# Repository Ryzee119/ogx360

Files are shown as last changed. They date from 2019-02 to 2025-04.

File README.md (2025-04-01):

# ogx360 - Overview
  

If you like my work please consider a small donation<br>
<br>

The ogx360 is a small circuit board which allows you to use a range of modern USB controllers on the Original Xbox Console.

* A simple video showing some its feature is on youtube https://youtu.be/ycZjQUjz1Fk
* Another video attempting to show the input lag is here: https://youtu.be/V7Pnba7Y12Y
* Another video showing the Steel Battalion Controller support is here: https://youtu.be/g_eQlOcccg8

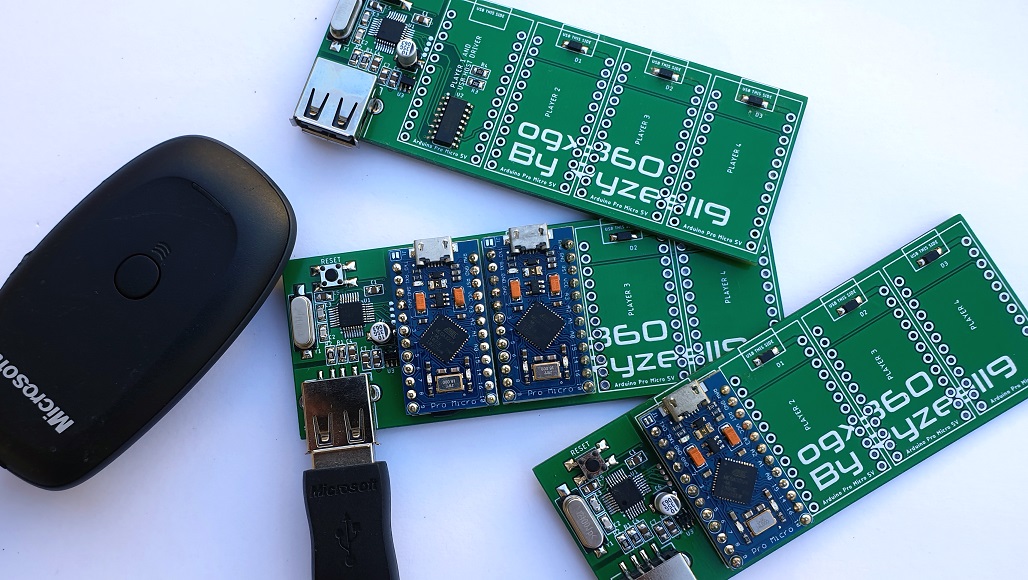
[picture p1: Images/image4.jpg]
ogx360 banner
  

## Features include:
* Full rumble support on all controllers.
* Steel Battalion controller support with an Xbox 360 Chatpad using Xbox 360 Wireless Controllers.
* Low level programming with minimal input lag. Less than 4ms over an original controller. (See https://youtu.be/V7Pnba7Y12Y)
* Firmware can be updated over USB. No programming hardware is required. See [Firmware](./Firmware).
* One ogx360 mutliple Xboxes, just plug the other Arduino modules into nearby OG Xbox consoles.
* Flip the axis on the right stick for those games missing axis inversion settings. (Hold the right stick in then D-PAD to invert that direction).

## Supported controllers
* Supports 4 players with Genuine and Third Party Microsoft Xbox 360 Wireless Receivers.
* Wired Xbox 360 Controllers.
* 8bitdo Wireless Bluetooth Adaptor (See http://www.8bitdo.com/wireless-usb-adapter/ for supported controllers). One controller per 8bitdo adaptor.
* ChronusMAX/ChronusZen (See https://cronusmax.com/ for supported devices). Ensure it is configured to appear as an Xbox 360 Controller. One controller per adaptor.
* Most/all? controllers that are xinput compatible.
* Genuine and PDP Wired Xbox One Controllers.
* Hyperkin Duke Xbox One Controller.
* **NOTE** - When connecting multiple USB bus powered devices, a USB2.0 hub is required. A externally powered hub is recommended.

## Steel Battalion controller emulation
* You need a wireless Xbox 360 controller with a chatpad peripheral.
* You can change what the controller appears to the console at anytime, so you can use the 'Duke Controller' to boot into the game, then change to the 'Steel Battalion controller' whilst in game. 
* Button mapping is below. (High Res image available [here](https://i.imgur.com/12SawzC.png)).

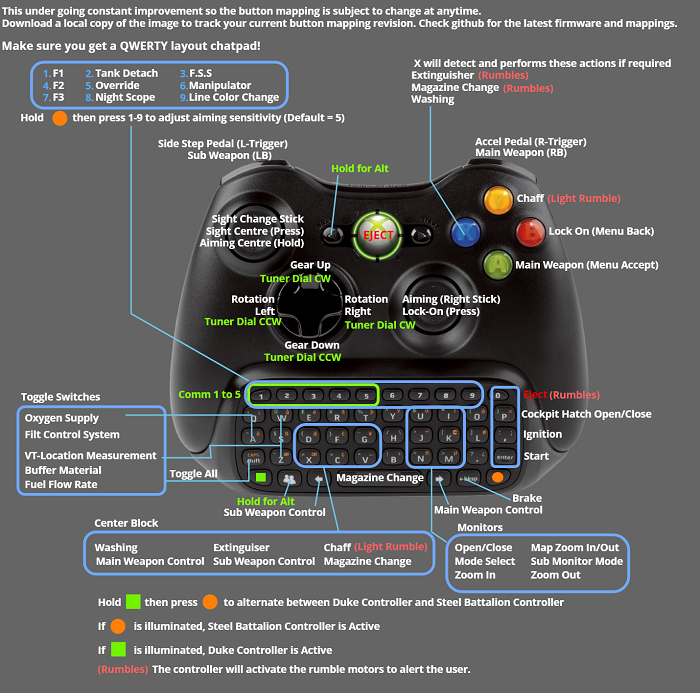
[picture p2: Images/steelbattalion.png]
sbmapping
  

## Connection to your Xbox
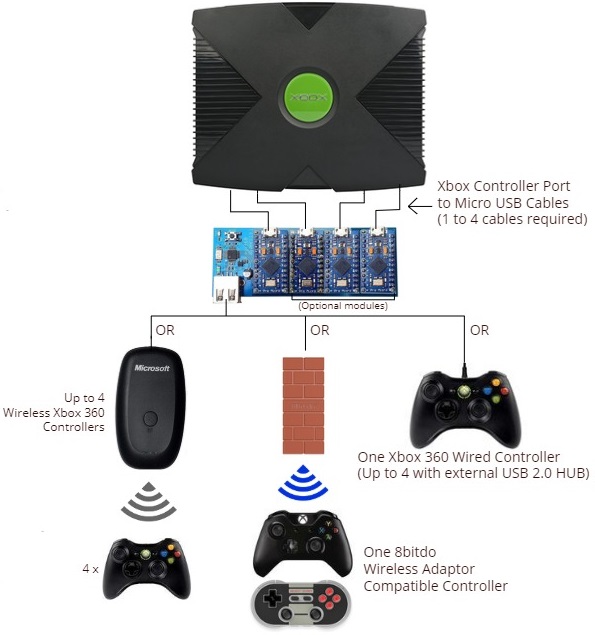
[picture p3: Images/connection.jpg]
connection diagram
  

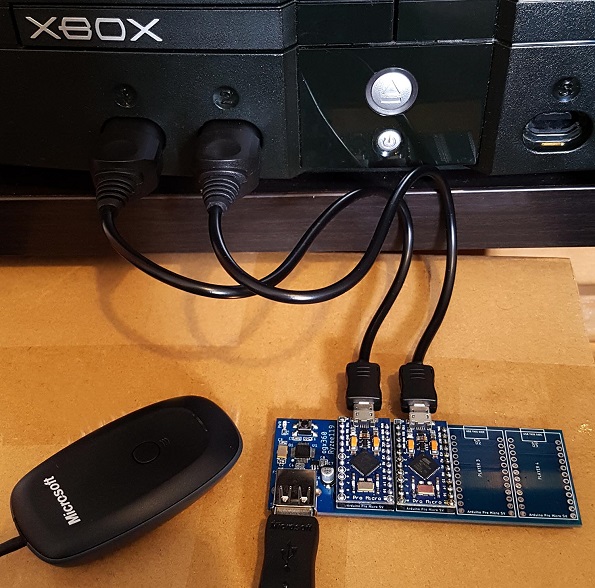
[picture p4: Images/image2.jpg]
ogx360 in use
  

By Ryzee119

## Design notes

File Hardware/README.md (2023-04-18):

# ogx360 - Hardware
This folder contains the schematic and PCB layout files and the PCB Gerber files. These were created using [Autodesk Eagle.](https://www.autodesk.com/products/eagle/overview)

* The PCB Gerbers and BOM are located [here](../.kitspace/).
* These can easily be ordered via [kitspace](https://kitspace.org/boards/github.com/ryzee119/ogx360).
  * Note: you may wish to order extra of the small components (resistors, capacitors, etc.) as it is easy to loose some when hand-soldering.
* 3D model of the PCB is [here](https://a360.co/3aavAXA) (Fusion360).
* Note: On the corner of the Arduino modules there is a solder jumper labelled J1. It is recommended you bridge this with a solder blob.

## Some other needed items
| Qty | Value/Model | Link|
| --- | --- | --- |
| Up to 4 | ARDUINO_LEONARDO_MICRO 5V/16Mhz | [Any clones](https://www.aliexpress.com/item/New-Pro-Micro-for-arduino-ATmega32U4-5V-16MHz-Module-with-2-row-pin-header-For-Leonardo/32768308647.html). Only one is compulsory. 2,3 and 4 will add support for Player 2,3, 4 respectively. Make sure you get the 5V/16Mhz variant. |
| Up to 4 | Xbox Controller Port to MicroUSB cable | [ChimericSystems](https://www.chimericsystems.com/product/micro-usb-to-xbox-cable/) or [Alibaba (Large MOQ!)](https://www.alibaba.com/product-detail/for-XBOX-MicroUSB-Cable-for-Xbox_62222784495.html) or DIY |

## Cases
If you make a case or something similar I can put it here if you're happy to share!
* By bluemeanie23 at [Tinkercad](https://www.tinkercad.com/things/kJb02GCUetG).
* By culexus at [Thingiverse](https://www.thingiverse.com/thing:3510779?fbclid=IwAR1Hd3BBLBxFbMWYJ0MO9VCzgxWrqV2Efiftj0Rz7HYnv9ODGwWncQdSh4I).

## Schematic
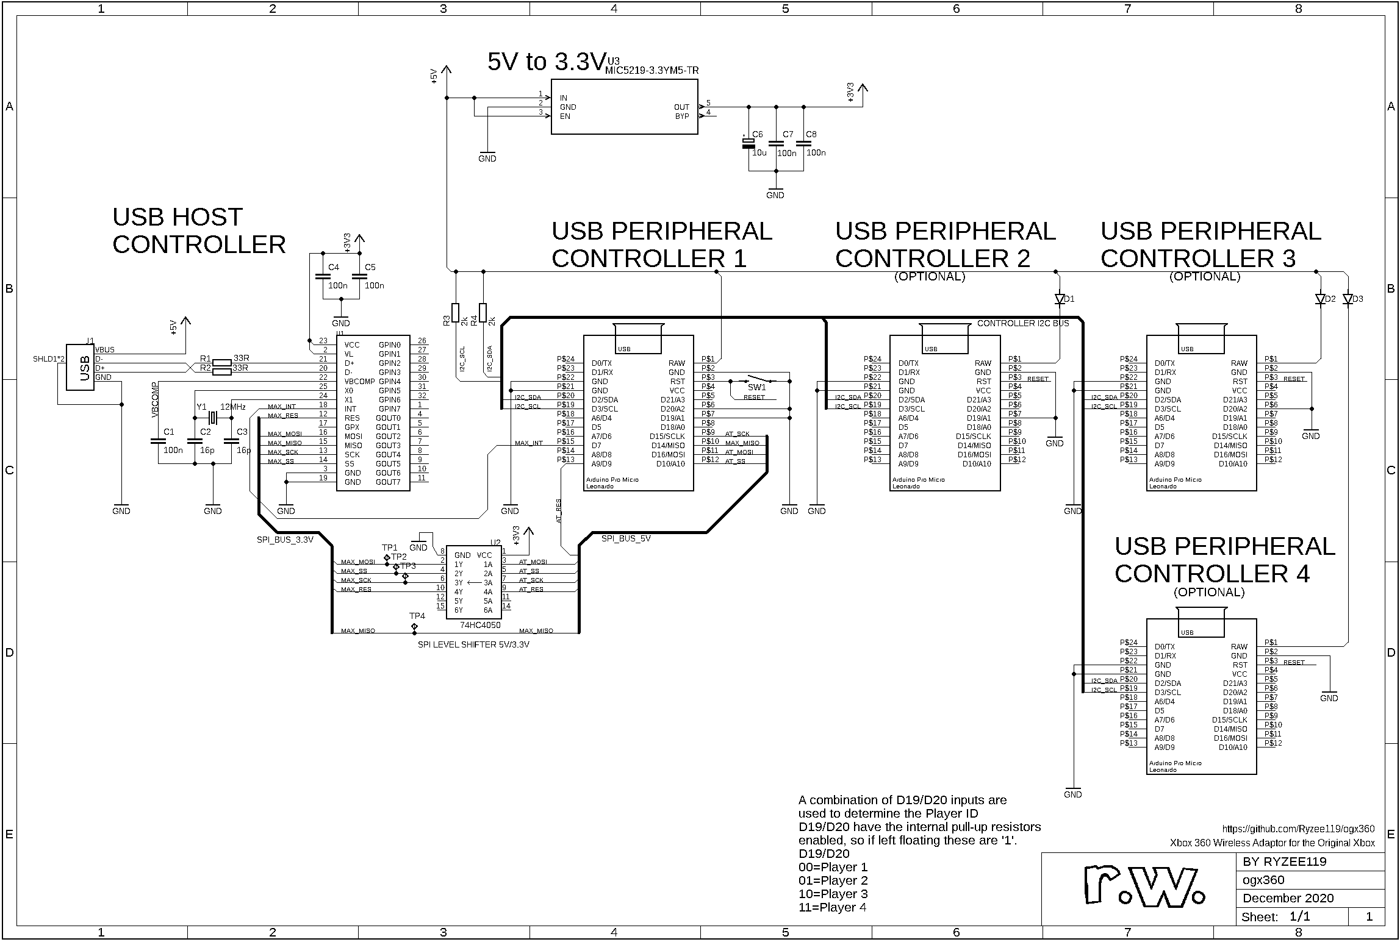
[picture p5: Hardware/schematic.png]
schematic


By Ryzee119

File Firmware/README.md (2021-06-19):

# ogx360 - Firmware

## Programming (Platform IO IDE - Recommended)
* Download and install [Arduino IDE](https://www.arduino.cc/en/software) for the required drivers.
* Setup Visual Studio Code as per the Compiling instructions.
* Press the RESET button on the ogx360 PCB.
* Hit the program button on the Platform IO toolbar (`→`).
* When the console window says `Waiting for the new upload port...` hit the RESET button again.
* Repeat the process for any other modules you need to update.

## Programming (from HEX file)
* Download and install [Arduino IDE](https://www.arduino.cc/en/software) for the required drivers.
* Download [avrdude](http://download.savannah.gnu.org/releases/avrdude/). Windows [download](http://download.savannah.gnu.org/releases/avrdude/avrdude-6.3-mingw32.zip).
* Create a file called `program.bat` in the same folder as `avrdude.exe` and copy this command into it. Note press RESET on the ogx360 and determine what COM number it appears in the device manager and alter the COM17 below as required.
* `avrdude -C avrdude.conf -F -p atmega32u4 -c avr109 -b 57600 -P COM17 -Uflash:w:ogx360.hex:i`
* Press RESET on the ogx360, wait a second then run the bat file.

## Compiling
* Download and install [Arduino IDE](https://www.arduino.cc/en/software) for the required drivers.
* Download and install [Visual Studio Code](https://code.visualstudio.com/).
* Install the [PlatformIO IDE](https://platformio.org/platformio-ide) plugin.
* Clone with git `git clone https://github.com/Ryzee119/ogx360.git --recursive`. Recursively!
* In Visual Studio Code `File > Open Folder... > ogx360/Firmware`
* Hit build on the Platform IO toolbar (`✓`).
* Follow the Programming instructions to program.
* Or see the `.pio/build/` folder for the compiled hex files.

## Testing
If you have made the board yourself and want to check everything is healthy, I have added a test program `ogx360_debug.hex`. Program this to the master module as per the programming instructions under **Programming**.

The module will now appear as a keyboard and serial device in windows. Note the COM port number.

Open a serial monitoring program such as [Termite](https://www.compuphase.com/software_termite.htm), and set the following settings `Baud rate: 115200, 8 Data Bits, 1 Stop Bit, Parity None, Flowing Control RTS/CTS`. Once you connect to the COM Port, the self test should be performed. A healthy board with a Wireless Receiver connected should output the following:

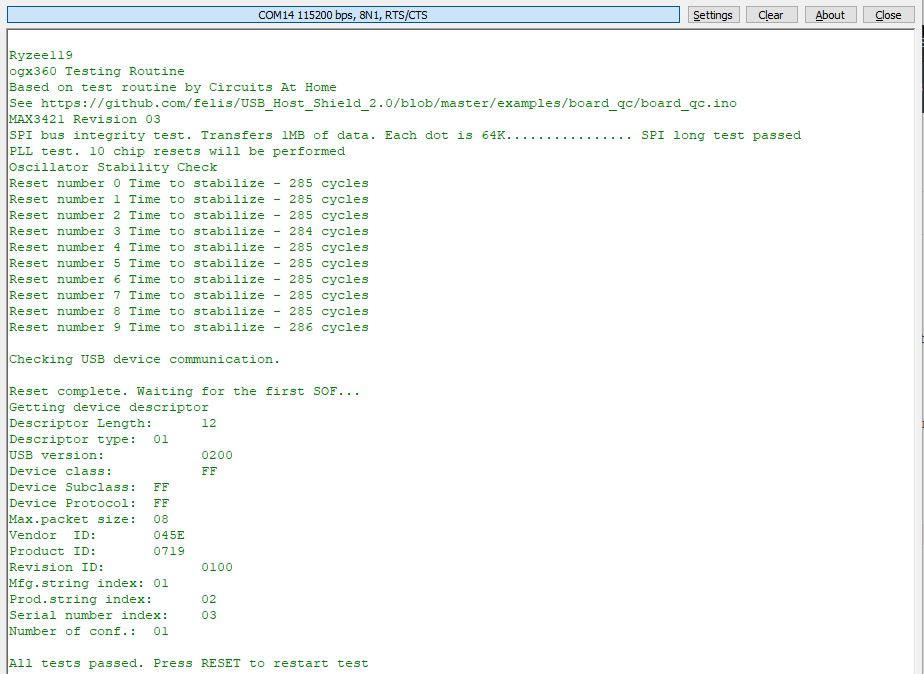
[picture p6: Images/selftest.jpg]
connection diagram
  

## References
* Xbox USB protocol info can be found [here](https://xboxdevwiki.net/Xbox_Input_Devices).
* [USB Host Shield 2.0](https://github.com/felis/USB_Host_Shield_2.0) Library use under the GNU General Public License.
* [Arduino Core](https://github.com/Ryzee119/ArduinoCore-avr) used under the [GNU General Public License/ Lesser GPL](https://github.com/arduino/Arduino/blob/master/license.txt).

By Ryzee119

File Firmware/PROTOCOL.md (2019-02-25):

# Original Xbox Controller USB Protocol Notes
The Original Xbox Controllers actually have a inbuilt 3 port USB hub. One channel is connected to the controller and the other two connect to the expansion ports on top of the controller.

The controller basically is a standard 'Human Input Device Class' as defined by the [USB Definition](https://www.usb.org/hid), however implement some custom vendor requests and are required for the controller to be detected correctly on an Original Xbox Console. The Original Xbox controller also does not have a HID Report Descriptor, consequently will not work in a Windows machine via a USB adaptor without custom drivers.
My code does not emulate the USB Hub and enumerates as the controller directly. The Xbox console doesn't seem to care.

A device descriptor dump from my Original Controller can be seen [here](https://github.com/Ryzee119/ogx360/tree/master/Firmware/DescriptorDump_VID045E_PID0289.md). There's a few variations around the world it seems, infact my own two controllers had slightly different descriptors but I guess all would work the same.
The device descriptor and the below responses are coded in `dukecontroller.h`.

### USB Controller Descriptor
Information for device USB\Vendor_045E_Product_0289:

Connection Information:
------------------------------
Device current bus speed: FullSpeed

Device supports USB 1.1 specification

Device address: 0x000B

Current configuration value: 0x01

Number of open pipes: 2

Device Descriptor:
------------------------------
0x12	bLength

0x01	bDescriptorType

0x0110	bcdUSB

0x00	bDeviceClass      

0x00	bDeviceSubClass   

0x00	bDeviceProtocol   

0x08	bMaxPacketSize0   (8 bytes)

0x045E	idVendor

0x0289	idProduct

0x0121	bcdDevice

0x00	iManufacturer

0x00	iProduct

0x00	iSerialNumber

0x01	bNumConfigurations

Configuration Descriptor:
------------------------------
0x09	bLength

0x02	bDescriptorType

0x0020	wTotalLength   (32 bytes)

0x01	bNumInterfaces

0x01	bConfigurationValue

0x00	iConfiguration

0x80	bmAttributes   (Bus-powered Device)

0x32	bMaxPower      (100 mA)

Interface Descriptor:
------------------------------
0x09	bLength

0x04	bDescriptorType

0x00	bInterfaceNumber

0x00	bAlternateSetting

0x02	bNumEndPoints

0x58	bInterfaceClass      

0x42	bInterfaceSubClass   

0x00	bInterfaceProtocol   

0x00	iInterface

Endpoint Descriptor:
------------------------------
0x07	bLength

0x05	bDescriptorType

0x81	bEndpointAddress  (IN endpoint 1)

0x03	bmAttributes      (Transfer: Interrupt / Synch: None / Usage: Data)

0x0020	wMaxPacketSize    (1 x 32 bytes)

0x04	bInterval         (4 frames)

Endpoint Descriptor:
------------------------------
0x07	bLength

0x05	bDescriptorType

0x02	bEndpointAddress  (OUT endpoint 2)

0x03	bmAttributes      (Transfer: Interrupt / Synch: None / Usage: Data)

0x0020	wMaxPacketSize    (1 x 32 bytes)

0x04	bInterval         (4 frames)

Microsoft OS Descriptor is not available. Error code: 0x0000001F

String Descriptor Table
--------------------------------
Index  LANGID  String

0x00   0x0000  

### HID Input Report (The data that is sent to the host when the host requests the HID Report)
| byte | Data |
| --- | --- |
| 00 | 0x00 - Always 0x00 |
| 01 | 0x14 - Size of the report. 0x14 = 20 bytes long |
| 02 | Each bit in the byte represents the Controller digital buttons.*|
| 03 | 0x00 - Always 0x00 |
| 04 | A Button (Analog button, unsigned char) 0x00 to 0xFF |
| 05 | B Button (Analog button, unsigned char) 0x00 to 0xFF |
| 06 | X Button (Analog button, unsigned char) 0x00 to 0xFF |
| 07 | Y Button (Analog button, unsigned char) 0x00 to 0xFF |
| 08 | BLACK Button (Analog button, unsigned char) 0x00 to 0xFF |
| 09 | WHITE Button (Analog button, unsigned char) 0x00 to 0xFF |
| 10 | L Trigger (Analog button, unsigned char) 0x00 to 0xFF |
| 11 | R Trigger (Analog button, unsigned char) 0x00 to 0xFF |
| 12/13 | Left Stick X-Axis (Analog, signed short 16-bit) |
| 14/15 | Left Stick Y-Axis (Analog, signed short 16-bit) |
| 16/17 | Right Stick X-Axis (Analog, signed short 16-bit) |
| 18/19 | Right Stick Y-Axis (Analog, signed short 16-bit) |

\* bit 0 to bit 7 = D-Pad Up, D-Pad Down, D-Pad Left, D-Pad Right, Start, Back, Left Stick Button, Right Stick Button

## HID Output Report (The data that is sent from the host. i.e rumble updates)
| byte | Data |
| --- | --- |
| 00 | 0x00 - Always 0x00 |
| 01 | 0x06 - Size of the report. 6 bytes long |
| 02 | 0x00 - Always 0x00 |
| 03 | Left Rumble Value (Analog, unsigned char) 0x00 to 0xFF |
| 04 | 0x00 - Always 0x00 |
| 05 | Right Rumble Value (Analog, unsigned char) 0x00 to 0xFF |

## XID Descriptor - Custom Vendor Request
This is what I obtained when monitoring the USB bus between the controller and the console.
The controller responds with this when `bmRequestType = 0xC1, bRequest = 0x06 and wValue = 0x4200` from the host.

| byte | Data |
| --- | --- |
| 00 | 0x10 - bLength, Length of report. 16 bytes |
| 01 | 0x42 - bDescriptorType, always 0x42 |
| 02 & 03 | 0x00, 0x01 - bcdXid  |
| 04 | 0x01 - bType - 1=Xbox Gamecontroller, 0x80 = Steel Battalion |
| 05 | 0x02 - bSubType, 0x01 = Gamepad (Duke), 0x02 = Gamepad S/Steel Battalion, 0x10 = Wheel.. |
| 06 | 0x14 - bMaxInputReportSize |
| 07 | 0x06 - bMaxOutputReportSize |
| 08 to 15 | 8 x 0xFF - wAlternateProductIds |

## HID Capabilities IN - Custom Vendor Request
This is what I obtained when monitoring the USB bus between the controller and the console.
The controller responds with this when `bmRequestType = 0xC1, bRequest = 0x01 and wValue = 0x0100` from the host.
It will have bits set (1) where the bit is valid in the HID Input Report.
If the bit is auto-generated, it will be cleared (0). Refer http://xboxdevwiki.net/Xbox_Input_Devices

| byte | Data |
| --- | --- |
| 00 | 0x00 - Always 0x00 |
| 01 | 0x14 - Size of the report. 0x14 = 20 bytes long |
| 02 | 0xFF |
| 03 | 0x00 |
| 04 to 19 | 16 x 0xFF |

## HID Capabilities OUT - Custom Vendor Request
This is what I obtained when monitoring the USB bus between the controller and the console.
The controller responds with this when `bmRequestType = 0xC1, bRequest = 0x01 and wValue = 0x0200` from the host.
It will have bits set (1) where the bit is valid in the HID Output Report.
If the bit is auto-generated, it will be cleared (0). Refer http://xboxdevwiki.net/Xbox_Input_Devices

| byte | Data |
| --- | --- |
| 00 | 0x00 - Always 0x00 |
| 01 | 0x06 - Size of the report. 6 bytes long |
| 02 to 05 | 4 x 0xFF |

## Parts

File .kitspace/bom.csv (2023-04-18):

Reference | Qty | Description | Part Number | Manufacturer | Digikey
C1,C4,C5,C7,C8 | 5 | CAP 100NF, 0805 | CC0805ZRY5V9BB104 | Yageo | 311-1361-1-ND
C2,C3 | 2 | CAP 16PF, 0805 | CC0805JRNPO9BN160 | Yageo | 311-4228-1-ND
C6 | 1 | CAP ALUM, 10UF SMD | EDK106M035A9BAA | KEMET | 399-14794-1-ND
D1,D2,D3 | 3 | DIODE SCHOTTKY, SOD123 | BAT54GWJ | Nexperia USA Inc. | 1727-7328-1-ND
J1 | 1 | USB CONNECTOR, TYPEA, SMD | AU-Y1006 | Assmann WSW Components | AE11182-ND
R1,R2 | 2 | RES, 33OHM, 1%, 0805 | RC0805FR-0733RL | Yageo | 311-33.0CRCT-ND
R3,R4 | 2 | RES, 2KOHM, 0805 | RC0805JR-072KL | Yageo | 311-2.0KARCT-ND
SW1 | 1 | SWITCH TACTILE SPST-NO | TL3305AF160QG | E-Switch | EG5350CT-ND
Y1 | 1 | CRYSTAL 12.0000MHZ 18PF SMD | J49SMH-F-G-G-K-12M0 | Jauch Quartz | 1908-J49SMH-F-G-G-K-12M0CT-ND
U1 | 1 | MAX3421 USB HOST CNTRL 32TQFP | MAX3421EEHJ+T | Maxim Integrated | MAX3421EEHJ+TCT-ND
U2 | 1 | IC BUFFER NON-INVERT 16SOIC | 74HC4050D | Toshiba Semiconductor and Storage | 74HC4050DCT-ND
U3 | 1 | IC REG LINEAR 3.3V 500MA SOT23-5 | MIC5219-3.3YM5-TR | Microchip Technology | 576-1281-1-ND

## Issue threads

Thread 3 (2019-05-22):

Rumble makes controller disconnect

TEK-Nemesis, 2019-05-22:
Area 51 with rumble on makes the controller disconnect on every rumble.  Turning rumble off solves the issue.

Only one wireless controller was connected.
Rev 1.0 board.  128MB RAM.  X3CE modchip using X2 5035.
Genuine Xbox 360 controller with genuine receiver.

Ryzee119, 2019-05-22:
Thanks foe the feedback
Is it only that game? Have you tried new batteries in the wireless controller?

TEK-Nemesis, 2019-05-22:
I only tried that game last night.

One battery (Panasonic alkaline) is at 1.52v; the other is at 1.14v (for a total of 2.66v).  Will replace both with Duracell alkaline batteries at 1.61v each (for a total of 3.22v).

(My gut feeling is that this will work.  I'll report back once tested.)

TEK-Nemesis, 2019-05-22:
Area 51 tests perfectly with rumble.  Thanks for your quick assessment!

Ryzee119, 2019-05-23:
No problem, I will look into mayble disabling rumble on low battery levels automatically to prevent this happening and extend controller life

Closed 2019-05-22.

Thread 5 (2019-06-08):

Grey 8Bitdo USB Adapter Support

SlowCatalyst, 2019-06-08:
Is the grey 8bitdo USB adapter supported as well?

I remember talking with you recently about the n360, in that there was a possibility of 8bitdo USB adapters being implemented to the firmware, but the grey model was a bit up in the air.

I just received my ogx360 [this thing is fkn beautiful by the way- amazing job]- hooked up the grey 8bitdo USB adapter, and NES30 Pro connected to it fine, however there is no input detected.

Am I missing a simple step, or does the grey USB infact have a different device signature- or something of that nature- from the orange variant USB adapter?

Ryzee119, 2019-06-08:
Only the orange adaptor has been tested.
If you can provide a usb descriptor dump from a windows PC and I can have a look at it to see how it differs.
I dont own a grey one to test

Evelsnake, 2019-08-03:
[DescriptorDump_Controller.txt](https://github.com/Ryzee119/ogx360/files/3463269/DescriptorDump_Controller.txt)

Information for device Controller (VID=0x054C PID=0x0CDA):

Connection Information:
------------------------------
Device current bus speed: FullSpeed
Device supports USB 1.1 specification
Device supports USB 2.0 specification
Device address: 0x0002
Current configuration value: 0x01
Number of open pipes: 2

Device Descriptor:
------------------------------
0x12	bLength
0x01	bDescriptorType
0x0200	bcdUSB
0x00	bDeviceClass
0x00	bDeviceSubClass
0x00	bDeviceProtocol
0x40	bMaxPacketSize0   (64 bytes)
0x054C	idVendor
0x0CDA	idProduct
0x0100	bcdDevice
0x01	iManufacturer   "Sony Interactive Entertainment"
0x02	iProduct   "Controller"
0x00	iSerialNumber
0x01	bNumConfigurations

Configuration Descriptor:
------------------------------
0x09	bLength
0x02	bDescriptorType
0x003B	wTotalLength   (59 bytes)
0x02	bNumInterfaces
0x01	bConfigurationValue
0x00	iConfiguration
0xA0	bmAttributes   (Bus-powered Device, Remote-Wakeup)
0x32	bMaxPower      (100 mA)

Interface Descriptor:
------------------------------
0x09	bLength
0x04	bDescriptorType
0x00	bInterfaceNumber
0x00	bAlternateSetting
0x01	bNumEndPoints
0x03	bInterfaceClass      (Human Interface Device Class)
0x00	bInterfaceSubClass
0x00	bInterfaceProtocol
0x00	iInterface

HID Descriptor:
------------------------------
0x09	bLength
0x21	bDescriptorType
0x0111	bcdHID
0x00	bCountryCode
0x01	bNumDescriptors
0x22	bDescriptorType   (Report descriptor)
0x0031	bDescriptorLength

Endpoint Descriptor:
------------------------------
0x07	bLength
0x05	bDescriptorType
0x81	bEndpointAddress  (IN endpoint 1)
0x03	bmAttributes      (Transfer: Interrupt / Synch: None / Usage: Data)
0x0040	wMaxPacketSize    (1 x 64 bytes)
0x0A	bInterval         (10 frames)

Interface Descriptor:
------------------------------
0x09	bLength
0x04	bDescriptorType
0x01	bInterfaceNumber
0x00	bAlternateSetting
0x01	bNumEndPoints
0x03	bInterfaceClass      (Human Interface Device Class)
0x00	bInterfaceSubClass
0x00	bInterfaceProtocol
0x00	iInterface

HID Descriptor:
------------------------------
0x09	bLength
0x21	bDescriptorType
0x0110	bcdHID
0x00	bCountryCode
0x01	bNumDescriptors
0x22	bDescriptorType   (Report descriptor)
0x0032	bDescriptorLength

Endpoint Descriptor:
------------------------------
0x07	bLength
0x05	bDescriptorType
0x82	bEndpointAddress  (IN endpoint 2)
0x03	bmAttributes      (Transfer: Interrupt / Synch: None / Usage: Data)
0x0040	wMaxPacketSize    (1 x 64 bytes)
0x0A	bInterval         (10 frames)

Microsoft OS Descriptor is not available. Error code: 0x0000001F

String Descriptor Table
--------------------------------
Index  LANGID  String
0x00   0x0000  0x0409
0x01   0x0409  "Sony Interactive Entertainment"
0x02   0x0409  "Controller"

------------------------------

Connection path for device:
Intel(R) 6 Series/C200 Series Chipset Family USB Enhanced Host Controller - 1C26
Root Hub
Generic USB Hub
Controller (VID=0x054C PID=0x0CDA) Port: 5

Running on: Windows 10 or greater

Brought to you by TDD v2.11.0, Mar 26 2018, 09:54:50

Ryzee119, 2019-08-03:
Thanks mate, appreciate it.
It enumerates as a PS Classic controller; this is currently not implemented and it's completely different from the Orange 8bitdo adaptor (which is supported). So won't work yet.

Doesn't look difficult to write a driver for it, but I won't be able to commit to anything yet. I'm also at the complete limits of Flash memory available

Ryzee119, 2019-08-11:
ok as a workaround in the interim, if anyone has the grey 8btido adaptor, I have a theory that the firmware from the orange unit can be written to it.
You can download the firmware for the orange unit from here:
https://support.8bitdo.com/

It is completely reversible.

I have tested converting my orange adaptor to the grey one myself. But no this way around. I assume it works the same.

CroCop86, 2019-08-11:
I have flashed the orange Firmware to the grey unit, but ogx360 won't recognize it

Ryzee119, 2019-08-11:
Thanks for testing @CroCop86. Well there goes that theory 😄 . I will be getting the grey adaptor soon so can do some testing from it too

Ryzee119, 2019-08-24:
So I got my grey adaptor and if I manually update the firmware with the firmware for the Orange adaptor it works for me https://download.8bitdo.com/Firmware/Receiver/usb_adapter/8BitDo_USB_RR_Firmware_V1.27.zip

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

Ryzee119, 2019-08-24:
If it doesn't work try updating to the latest firmware. I have improved some timings which may make a difference.

Kilerz28, 2020-01-18:
Hey. I have done what you said here @Ryzee119 and it works for me. I have the gray adapter and it pairs with my xbox one controller. Thanks.

Ryzee119, 2020-03-15:
Closed, as it is simple to write the orange/brown unit fimmware to the grey device so that it works.

Closed 2020-03-15.

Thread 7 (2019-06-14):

Migrate to UHS3.0

Ryzee119, 2019-06-14:
Currently the ogx360 firmware uses the USB Host Shield 2.0 library. This is polling based and has lots of inherent issues meeting USB timing specifications. It has many hacks to get things reliably working. Endpoints writes dont always work as expected (i.e the wrong controller rumbles or the LED's dont work correctly)

UHS3.0 is interrupt driven and does not suffer from these inherent problems. Ideal plan is to migrate the code to this new library.
Challenges:
UHS3 does not have any Xbox drivers - these will need to be created and ideally upstreamed
ogx360 max3421 interrupt pin isnt actually connected to the Arduino on the PCB (I should have planned ahead better!) . work around?
Significant rewrite required but hopefully a much more reliable solution.

Ryzee119, 2020-12-08:
Ive ported UHS3 and got it running, however the 32u4 just doesnt have enough RAM to get it working.
It fails on most memory allocations and this is before ive even added in the device stack.

I unfortunately dont think it is possible to put this on the 32u4 :(

Closed 2020-12-08.

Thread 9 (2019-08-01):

3 pad RED LED 67-1556-1-ND

tai1976, 2019-08-01:
Had some boards made up from OSHPark and used your Digikey quick cart and everything went and works well. However, the 3 pad RED LED 67-1556-1-ND has really thrown me for a loop.
I believe the center pad is for heat dissipation which can increase brightness at lower voltages and the overall life of the LED but your PCB layout only has 2 pads for the anode and cathode and I was concerned the center pad could possibly short both pads.
So my question is this. Why use a 3 pad LED with only 2 pads on the PCB?
Was 67-1556-1-ND originally a 2 pad LED? Should I solder the LED a bit off center so that the center pad dissipates through the anode or cathode or am I just missing something?

Ryzee119, 2019-08-02:
That's interesting, 67-1556-1-ND wasn't a 3-pad LED in my prototyping from memory.
It's unclear exactly what that 3rd pad is, just mechanical support I guess, and some heat dissipation but that wont be a concern for this.

I'd say that centre pad can remain unconnected. I will update that part to a more standard 0805 LED. It wont impact the operation of the board in anway, purely a power indication LED (But the arduinos have this anyway)

Thank you for highlighting the issue.

tai1976, 2019-08-02:
Thank you for getting back. That is what I thought. I just used a standard 0603 LED I already had on hand and swapped R5 for a 220 Ohm resistor to increase the brightness.
Thank you so much for making and publishing this project. This is truly a must have/make for any OG Xbox fan.

Ryzee119, 2019-08-03:
Closed by PR #9fa276d

Closed 2019-08-03.

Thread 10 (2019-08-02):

generic wireless adapter not syncing

loggio, 2019-08-02:
Hi, @Ryzee119

I have obtained an OGX360 and can't thank you enough for all your hard work. It's awesome!

I'm having issues however... I have a generic wireless adapter off eBay.
It will allow me to sync 3 of my xbox 360 controllers to the OGX360, but the other 4 controllers i have do not sync. Funny enough all of the controllers that i cannot get to sync are all white version controllers (could be just coincidence). Maybe they're older models??

I suspect that your driver support is not working for certain versions of the 360 controller. A handshake miss-match so to speak.

When the ogx360 is plugged in to the control ports of the XBOX, i push the sync buttons and the controller will acknowledge the dongle as it stops the sync process and begins the quick pulse handshake, the master controller of the OGX360 will briefly flash red and then disappear as if it cannot pair with the controller.... This loop continues over and over until the controller battery is pulled.

If i plug this receiver into my windows 10 computer and install the genuine microsoft driver for the dongle, i can sync the controllers just fine to my PC.

All of my controllers work perfectly and sync with the PC and the XBOX 360. But only 4 out f my 7 controllers will sync successfully with the OGX360, the other 3 will not.

Is there any information i can supply you that will help with diagnosing this problem ?
hopefully a firmware update will fix this.

Ryzee119, 2019-08-02:
Hey mate,
Thanks for the details response.
Its possible there is some differences that Im not aware of.

Out of curiosity, the controllers that don't appear to sync, have you checked if the buttons etc. actually work still?
Its possible its just the LED thats not setting to a quadrant correctly.

If the controllers don't work at all we can look into it a bit further

loggio, 2019-08-02:
They don't work at all. The controllers will recognise the dongle but won't sync at all.

Ryzee119, 2019-08-02:
My understanding was that all the syncing and negotiations was handled by the receiver. The driver doesn't do any of that so this is an interesting one.

I'll have to do some digging this weekend to see how the windows driver handshakes and if im doing anything differently.

loggio, 2019-08-02:
Yes it's weird. They're all genuine controllers. The only thing different is the Chinese dongle. Though like I said, the same dongle syncs the controllers fine on Windows pc.

And the controllers sync fine on my xbox 360. Just not the Ogx360.

Let me know if you need me to do any further testing.

Ryzee119, 2019-08-06:
So i've dumped the USB traffic going to the wireless receiver in Windows on connection of the Xbox 360 controller.

The following packets are sent to the respective endpoint (1,3,5 or 7 depending on the controller)
00 00 08 40 00 00 00 00 00 00 00 00 //Turn LED off

00 00 08 42 00 00 00 00 00 00 00 00 //Set LED to blink. 0x42 is for quadrant 1

00 00 02 80 00 00 00 00 00 00 00 00 //Unknown?

00 00 00 40 00 00 00 00 00 00 00 00 //Update battery level I think

00 00 08 46 00 00 00 00 00 00 00 00 //Set LED to solid on for quadrant 1

It also polls every 2.5 seconds, but I think this is just to update the battery level or some kind of status to the windows driver.

I have implemented this init sequence exactly as per the windows driver

[ogx360_issue10.zip](https://github.com/Ryzee119/ogx360/files/3471615/ogx360_issue10.zip)

If you are able to test this firmware and report back that would be awesome!

Programming instructions are here

https://github.com/Ryzee119/ogx360/tree/master/Firmware#programming

loggio, 2019-08-06:
just tested and still no difference. Cannot sync

loggio, 2019-08-06:
i do have a microsoft branded dongle coming in the mail... When i receive that i will test and report back. Will be interesting if it is the dongle.

But as i said, the dongle works fine on the PC syncing with all my controllers using the official microsoft drivers. So not sure what could be causing this.

The controllers seem to sync with the dongle, but they won't latch on to a port. you can see that one micro controller will light up for briefly and then disappear

Ryzee119, 2019-08-06:
Thanks for your prompt testing
That will be very interesting to see if the genuine one works
I'm also curious to know if it works in Linux as my driver is loosely based on the xpad driver in Linux.

loggio, 2019-08-06:
Ok,  I can test on Ubuntu. Hopefully it's just plug and play. I will do this tomorrow.

loggio, 2019-08-06:
So, just to summaries...

 My steps

1. Turn on xbox. Wait for boot.
2. Attach dongle
3. Attach master to Port 1 of xbox
4. Turn on controller, press sync.
5. Press sync on dongle.

Results.

After pressing sync on both controller and dongle, the controller will very quickly sync with the dongle as the controller stops the sync cycle and starts to flash.

I see the master controller of the Ogx360 flash red briefly, but won't latch on. The controller will just sit in a pairing (flashing) state until switched off. Slave controllers act the same.

The handshake between the controller, dongle and Port assignments seems to not want to cooperate.

It sounds very much like I'm using different versions of controllers and some of which are incompatible with the drivers.

I just can't see why some controllers work fine, and others won't.

Ryzee119, 2019-08-06:
Thanks for the summary, I'll have a think about it and see if I can come up with anything in the meantime too

loggio, 2019-08-07:
So, i've layed out all my controllers. the three white controllers stacked are the ones that do not work.

Interestingly enough, they are a different model number to the rest - model MSK-WC01

The black controllers and the silver controllers are model number MSK-1403
The single white controller is model number  MSK-XBOX360WLSCTLR

All work on PC and seem to sync with the dongle.
only model number MSK-WC01 will not work with your OGX360.

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

I have yet to try with Ubuntu. Will do this shortly.

loggio, 2019-08-07:
Ok, the controller syncs and works fine on Ubuntu.
See videos below.

[videos.zip](https://github.com/Ryzee119/ogx360/files/3475838/videos.zip)

Ryzee119, 2019-08-07:
legend mate, thanks once again for the detailed response. I'll review/test and see what I come up with!
Unfortunately all my controllers are MSK-1403, so there's something interesting going on with that model I guess

loggio, 2019-08-07:
One thing I noticed is that it took a little while to assign a quadrant for the controller on Ubuntu... Maybe this model takes a little longer to sync up?

Might be a timing thing perhaps?

Ryzee119, 2019-08-09:
[ogx360_issue10_1.zip](https://github.com/Ryzee119/ogx360/files/3485933/ogx360_issue10_1.zip)
Ok, so I tweaked some timing to match the Windows driver more closely, and also changed all my packet sizes to 12 bytes.

Ryzee119, 2019-08-09:
You probably only need to update the MASTER device for this, so no need to update all modules

loggio, 2019-08-09:
Hmm it's still not working.

However, it seems to latch for a second or two longer and more frequently ... Enough to register a quadrant but won't lock on.

Ryzee119, 2019-08-09:
wow those are some picky controllers. I think I'm replicating the Windows driver exactly. Last thing to see is if the genuine receiver makes a difference

loggio, 2019-08-09:
It's definitely trying a lot harder

Ryzee119, 2019-08-09:
The controller's not turning off right? Just disconnecting?

loggio, 2019-08-09:
Hmm yes I can try this. It was due to be delivered today but I missed the delivery so I have to pick it up from the post office, however I'm working away next week so I won't be able to test it till I'm back for the weekend

loggio, 2019-08-09:
Just disconnecting, trying over and over to connect. I can see now it will connect, flash a quadrant, and then disconnect... Sometimes reconnecting again a second later only to disconnect again.

Ryzee119, 2019-08-09:
[ogx360_issue10_2.zip](https://github.com/Ryzee119/ogx360/files/3486046/ogx360_issue10_2.zip)
No worries, sorry to be bothering with different files but you could also try this one to see if it makes a difference

loggio, 2019-08-09:
So the symptoms have changed slightly, it's an improvement... Maybe the timing needs to be tweaked beyond default ms drivers?

loggio, 2019-08-09:
No difference

Ryzee119, 2019-08-09:
thanks again, I might see if I can source one of these controllers or ask around if anyone can test their ogx360 with that revision.

loggio, 2019-08-09:
And you're not bothering me mate, happy to be testing. You can keep sending me files

loggio, 2019-08-09:
No way! It just synced.

I waited for a quadrant to flash and then quickly pushed a button and it locked on and stayed connected.

Once I turn the controller off and back on  it struggles to connect again

Ryzee119, 2019-08-09:
Does it help if you're moving an analog stick around whilst it is syncing?
This forces the controller to send interrupt transfers and might help it connect

loggio, 2019-08-09:
I haven't been able to get it to sync again. I can try this again

loggio, 2019-08-09:
Didn't help...

loggio, 2019-08-09:
In case you're interested
This is the dongle I purchased.
https://rover.ebay.com/rover/0/0/0?mpre=https%3A%2F%2Fwww.ebay.com.au%2Fulk%2Fitm%2F322228480691

loggio, 2019-08-09:
Also,

If you're interested, I've found 3 ebay listing with the controller. 1# finishing later today. All buy it now.

1. https://rover.ebay.com/rover/0/0/0?mpre=https%3A%2F%2Fwww.ebay.com.au%2Fulk%2Fitm%2F264316811936

2. https://rover.ebay.com/rover/0/0/0?mpre=https%3A%2F%2Fwww.ebay.com.au%2Fulk%2Fitm%2F143347474356

3. https://rover.ebay.com/rover/0/0/0?mpre=https%3A%2F%2Fwww.ebay.com.au%2Fulk%2Fitm%2F283557924170

Ryzee119, 2019-08-09:
Awesome, #1 ordered!

loggio, 2019-08-09:
Just make sure you ask the seller to make sure the model number is exactly as pictured!!!

I just noticed he has a max quantity of 2... Meaning he's selling more than one.

I've had it where the item they send is different to the one pictured.

loggio, 2019-08-10:
Ok, I'm very happy to report that I just picked up my official Microsoft adapter (post office is open for a few hours) and all the controllers sync up perfectly and instantly!

So it is definitely the cheap adapter.

Would still be good to continue troubleshooting this as I'm guessing in the future a lot of people will have no choice but to buy cheap adapters as the official ones are no longer available.

Ryzee119, 2019-08-10:
Fantastic news, I have this version of controller enroute and a few different receivers to try. If I can replicate the issue I should be able to solve it!

Ryzee119, 2020-12-14:
The XBOXRECV driver has been reworked significantly. If anyone had this issue please retry and report back.

Will close issue in a few weeks if no reports. Reopen if still present :)

Closed 2021-01-01.

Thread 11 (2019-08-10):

8Bitdo Adapter not working

CroCop86, 2019-08-10:
I have 2 orange and 2 grey 8Bitdo receiver and i can't get anyone to work. Can you help me please somehow?

I have attached the logfile from USB Descriptor Dumper as a textfile

[8Bitdo Receiver.txt](https://github.com/Ryzee119/ogx360/files/3489209/8Bitdo.Receiver.txt)

Ryzee119, 2019-08-11:
Hello,
Interestingly all the descriptor dumps provided look like they're  from a grey adaptor. Not an orange one.

Are these descriptor dumps being  taken from a windows machine?
The Orange adaptors traditionally, enumerate as a Xbox360 wired controller,
The greys enumerate as a generic Playstation controller.

I think I will need to pickup one of these grey units and add support for it.

Ryzee119, 2019-08-11:
You could try udating your orange 8bitdo device to the latest firmware https://support.8bitdo.com/firmware-updater.html

The grey unit is significantly different, so is not currently supported

CroCop86, 2019-08-11:
Thank you for your fast answer. I have updated all four to the latest firmware through the universal 8bitdo updater. I will try to flash them with their own updater:
8BitDo_USB_RR_Firmware_V1.26
8BitDo_USB_RR_FOR_PS_Firmware_V1.26

And maybe downgrade them. If you could add support for the grey ones too, would be really appreciate :)

CroCop86, 2019-08-11:
I have downgrade from Firmware v1.27 to v1.26, now the orange receiver work both. I have attached again the log File for you, so you can see what changed after the downgrade.

Thank you again for your help :)
[8Bitdo Orange after downgrade to FW 1.26.txt](https://github.com/Ryzee119/ogx360/files/3489730/8Bitdo.Orange.after.downgrade.to.FW.1.26.txt)

Ryzee119, 2019-08-11:
That log file looks much better.
So I just did some testing and it is actually possible to write the firmware for the grey unit onto the orange unit (causing incompatibility with the ogx360).
The auto update will then just assume the grey unit and auto update accordingly (and incorrectly).

I would assume now that if you run the auto update tool now that you've written the correct firmware it will work as expected.

I wonder if somehow the firmware got mixed up at some point

CroCop86, 2019-08-11:
I'm not sure how it got mixed up, but for the first time i tried the beta Firmware 1.27 and still the orange icon was shown above the updater. Maybe that was the problem. Downgrading to 1.26 for the orange unit resolved it however. Are you still planing to add support for the grey units?

Ryzee119, 2019-08-11:
I have ordered a grey unit so will see what I can do in the upcoming weeks

Ryzee119, 2019-08-11:
I will mark this issue as closed but will link existing issue #5 for grey 8bitdo adaptor support.

Closed 2019-08-11.

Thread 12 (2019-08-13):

404 on bill of materials usb controller link

RobertDaleSmith, 2019-08-13:
Thanks for the awesome work here. Looking into building my own unit and noticed one of the Digi-Key links is dead. Would this be a good alternative to the usb host controller?

https://www.digikey.com.au/product-detail/en/maxim-integrated/MAX3421EEHJ-T/MAX3421EEHJ-TTR-ND/1455882

Ryzee119, 2019-08-14:
Hello,

Looks good! However I suggest his link. The same part but allows single units to be purchased and is in stock.

https://www.digikey.com.au/product-detail/en/maxim-integrated/MAX3421EEHJ-T/MAX3421EEHJ-TCT-ND/4895460

I will update the parts list to fix the 404. Thanks for highlighting the issue.

Cheers

Ryzee119, 2019-08-14:
Digikey quick cart link seems to work ok still
https://www.digikey.com.au/short/pbnnjz

RobertDaleSmith, 2019-08-15:
This may seem redundant but.. Does the OGX360 support wired OG Xbox controllers connected with a Xbox controller to USB adapter? I remember years ago making a cable to use my original Xbox controller on a PC, so I assume it's possible.

The reason I ask is because I am brainstorming ideas for installing the OGX360 internally. I thought it would be neat to hack this in between the internal controller ports connector and the xbox's motherboard. Passing the front controller ports into a USB hub and then into the OGX360 and then OGX360 directly to the motherboard connections.

Ryzee119, 2019-08-28:
ogx360 doesnt support OG Xbox controllers currently. There exists a few options out there which have internal installations which use switching relays so that the front ports are still fully functional.
I will close this issue as I have resolved it in commit dd7d544.
Please raised another as an enhancement regarding og controllers.

Closed 2019-08-28.

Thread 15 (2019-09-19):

Another issue sycning with cheap third party adapter

caeberos, 2019-09-19:
I have a kinda crappy xbox 360 wireless adapter that I bought off ebay, it works perfectly when hooked up to my computer, but never quite syncs when I use it on the OGX360, I have three different controllers and none of them sync.    I have included the descriptor dump, and I have also flashed the OGX360 with the 2nd master hex dump included in the issue 10 thread, which didn't help.  If there is a pretty good 3rd party adapter I can get off ebay I wouldn't mind just ordering that to use it, I don't really want to spend $50 on the original Microsoft one, but I will if I need to :)

[DescriptorDump_XBOX360_cheap.txt](https://github.com/Ryzee119/ogx360/files/3628957/DescriptorDump_XBOX360_cheap.txt)

caeberos, 2019-09-19:
so slight correction, the controllers only sync when I am using linux, it remains an unknown device under windows, I am not planning on using this hooked up to my computer anyway, just thought it was worth mentioning

Ryzee119, 2019-09-20:
Thanks ill have a look at this soon. Theres alot of combinations of these clone adaptors and this just looks like another one.

caeberos, 2019-09-21:
thank you so much!  I am glad you are looking into this.  I can't wait to beat halo!!!!

Ryzee119, 2019-09-21:
Hi caeberos,
Please try version 1.2 here: https://github.com/Ryzee119/ogx360/releases

You can update it as per the instructions here: https://github.com/Ryzee119/ogx360/tree/master/Firmware#programming

Please you note you will ONLY need to update the master module. (I.e the  one closest to the big USB connector)

caeberos, 2019-09-22:
Works Perfectly!   I have only attempted one controller, but it syncs instantly, and also the Steel Batallion mode works perfectly as well!  Thank you so much!

Closed 2019-09-22.

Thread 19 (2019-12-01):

Mad Catz Street Fighter IV SE Fighting Stick

thehijjt, 2019-12-01:
I got excited when I saw an update with a madcatz id, unfortunately it didn't match up with my fight sticks, and the green ring just went dim. I attached the USB info below:

 idVendor=1bad, idProduct=f018, bcdDevice= 4.90
New USB device strings: Mfr=1, Product=2, SerialNumber=3
Product: Street Fighter IV FightStick
Manufacturer: Mad Catz, Inc.
SerialNumber: 0E7D6FB7

input: Mad Catz Street Fighter IV SE Fighting Stick

Ryzee119, 2019-12-02:
Can you provide the rest of the descriptor?
You can use a tool like this:

https://www.thesycon.de/eng/usb_descriptordumper.shtml

Cheers

thehijjt, 2019-12-02:
Information for device Street Fighter IV FightStick (VID=0x1BAD PID=0xF018):

Connection Information:
------------------------------
Device current bus speed: FullSpeed
Device supports USB 1.1 specification
Device supports USB 2.0 specification
Device address: 0x000F
Current configuration value: 0x01
Number of open pipes: 7

Device Descriptor:
------------------------------
0x12	bLength
0x01	bDescriptorType
0x0200	bcdUSB
0xFF	bDeviceClass      (Vendor specific)
0xFF	bDeviceSubClass
0xFF	bDeviceProtocol
0x08	bMaxPacketSize0   (8 bytes)
0x1BAD	idVendor
0xF018	idProduct
0x0490	bcdDevice
0x01	iManufacturer   "Mad Catz, Inc."
0x02	iProduct   "Street Fighter IV FightStick"
0x03	iSerialNumber   "0E7D6FB7"
0x01	bNumConfigurations

Configuration Descriptor:
------------------------------
0x09	bLength
0x02	bDescriptorType
0x0099	wTotalLength   (153 bytes)
0x04	bNumInterfaces
0x01	bConfigurationValue
0x00	iConfiguration
0xA0	bmAttributes   (Bus-powered Device, Remote-Wakeup)
0xFA	bMaxPower      (500 mA)

Interface Descriptor:
------------------------------
0x09	bLength
0x04	bDescriptorType
0x00	bInterfaceNumber
0x00	bAlternateSetting
0x02	bNumEndPoints
0xFF	bInterfaceClass      (Vendor specific)
0x5D	bInterfaceSubClass
0x01	bInterfaceProtocol
0x00	iInterface

Unknown Descriptor:
------------------------------
0x11	bLength
0x21	bDescriptorType
Hex dump:
0x11 0x21 0x10 0x01 0x03 0x25 0x81 0x14 0x03 0x03
0x03 0x04 0x13 0x02 0x08 0x03 0x03

Endpoint Descriptor:
------------------------------
0x07	bLength
0x05	bDescriptorType
0x81	bEndpointAddress  (IN endpoint 1)
0x03	bmAttributes      (Transfer: Interrupt / Synch: None / Usage: Data)
0x0020	wMaxPacketSize    (1 x 32 bytes)
0x04	bInterval         (4 frames)

Endpoint Descriptor:
------------------------------
0x07	bLength
0x05	bDescriptorType
0x02	bEndpointAddress  (OUT endpoint 2)
0x03	bmAttributes      (Transfer: Interrupt / Synch: None / Usage: Data)
0x0020	wMaxPacketSize    (1 x 32 bytes)
0x08	bInterval         (8 frames)

Interface Descriptor:
------------------------------
0x09	bLength
0x04	bDescriptorType
0x01	bInterfaceNumber
0x00	bAlternateSetting
0x04	bNumEndPoints
0xFF	bInterfaceClass      (Vendor specific)
0x5D	bInterfaceSubClass
0x03	bInterfaceProtocol
0x00	iInterface

Unknown Descriptor:
------------------------------
0x1B	bLength
0x21	bDescriptorType
Hex dump:
0x1B 0x21 0x10 0x01 0x01 0x01 0x83 0x40 0x01 0x04
0x20 0x16 0x85 0x00 0x00 0x00 0x00 0x00 0x00 0x16
0x05 0x00 0x00 0x00 0x00 0x00 0x00

Endpoint Descriptor:
------------------------------
0x07	bLength
0x05	bDescriptorType
0x83	bEndpointAddress  (IN endpoint 3)
0x03	bmAttributes      (Transfer: Interrupt / Synch: None / Usage: Data)
0x0020	wMaxPacketSize    (1 x 32 bytes)
0x02	bInterval         (2 frames)

Endpoint Descriptor:
------------------------------
0x07	bLength
0x05	bDescriptorType
0x04	bEndpointAddress  (OUT endpoint 4)
0x03	bmAttributes      (Transfer: Interrupt / Synch: None / Usage: Data)
0x0020	wMaxPacketSize    (1 x 32 bytes)
0x04	bInterval         (4 frames)

Endpoint Descriptor:
------------------------------
0x07	bLength
0x05	bDescriptorType
0x85	bEndpointAddress  (IN endpoint 5)
0x03	bmAttributes      (Transfer: Interrupt / Synch: None / Usage: Data)
0x0020	wMaxPacketSize    (1 x 32 bytes)
0x40	bInterval         (64 frames)

Endpoint Descriptor:
------------------------------
0x07	bLength
0x05	bDescriptorType
0x05	bEndpointAddress  (OUT endpoint 5)
0x03	bmAttributes      (Transfer: Interrupt / Synch: None / Usage: Data)
0x0020	wMaxPacketSize    (1 x 32 bytes)
0x10	bInterval         (16 frames)

Interface Descriptor:
------------------------------
0x09	bLength
0x04	bDescriptorType
0x02	bInterfaceNumber
0x00	bAlternateSetting
0x01	bNumEndPoints
0xFF	bInterfaceClass      (Vendor specific)
0x5D	bInterfaceSubClass
0x02	bInterfaceProtocol
0x00	iInterface

Unknown Descriptor:
------------------------------
0x09	bLength
0x21	bDescriptorType
Hex dump:
0x09 0x21 0x10 0x01 0x01 0x22 0x86 0x07 0x00

Endpoint Descriptor:
------------------------------
0x07	bLength
0x05	bDescriptorType
0x86	bEndpointAddress  (IN endpoint 6)
0x03	bmAttributes      (Transfer: Interrupt / Synch: None / Usage: Data)
0x0020	wMaxPacketSize    (1 x 32 bytes)
0x10	bInterval         (16 frames)

Interface Descriptor:
------------------------------
0x09	bLength
0x04	bDescriptorType
0x03	bInterfaceNumber
0x00	bAlternateSetting
0x00	bNumEndPoints
0xFF	bInterfaceClass      (Vendor specific)
0xFD	bInterfaceSubClass
0x13	bInterfaceProtocol
0x04	iInterface   "Xbox Security Method 3, Version 1.00, © 2005 Microsoft Corporation. All rights reserved."

Unknown Descriptor:
------------------------------
0x06	bLength
0x41	bDescriptorType
Hex dump:
0x06 0x41 0x00 0x01 0x01 0x03

Microsoft OS Descriptor:
------------------------------
0x12	bLength
0x03	bDescriptorType
Hex dump:
0x12 0x03 0x4D 0x00 0x53 0x00 0x46 0x00 0x54 0x00
0x31 0x00 0x30 0x00 0x30 0x00 0x90 0x00

String Descriptor Table
--------------------------------
Index  LANGID  String
0x00   0x0000  0x0409
0x01   0x0409  "Mad Catz, Inc."
0x02   0x0409  "Street Fighter IV FightStick"
0x03   0x0409  "0E7D6FB7"
0x04   0x0409  "Xbox Security Method 3, Version 1.00, © 2005 Microsoft Corporation. All rights reserved."

------------------------------

Connection path for device:
USB xHCI Compliant Host Controller
Root Hub
Generic USB Hub
Street Fighter IV FightStick (VID=0x1BAD PID=0xF018) Port: 2

Running on: Windows 10 or greater (Build Version 18362)

Brought to you by TDD v2.12.0, Aug  2 2019, 16:35:05

Ryzee119, 2019-12-02:
Thanks mate. Shouls be able to add it. Will let you know when i get around to it

Ryzee119, 2020-03-15:
Support hopefully added in V1.4 release
https://github.com/Ryzee119/ogx360/releases/tag/1.4

If anyone has this controller and can confirm it works, please report here

Ryzee119, 2020-07-03:
No report for 3 months.
Assuming all is working. Re-open a new issue if an issue is encountered with this controller.

Closed 2020-07-03.

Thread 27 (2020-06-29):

Firmware update not working - Windows 10.

mrDevGit, 2020-06-29:
Hi,

Amazing work, thanks for making this possible. It al works but I have no SB support at the moment.

Bought the full setup off Chimeric Systems. 4 boards with usb adapters.

I am trying to flash the firmware that will enable SB support.

However, when I connect the master board via USB it pops up as an "Unknown Device" on a WIndows 10 laptop.

It never shows up as a COM Port.

How do I resolve this?

Thanks

mrDevGit, 2020-06-30:
I thought the reset was just to give you another shot but you have to press reset really quickly after connecting via USB.

Works perfectly.

Ryzee119, 2020-06-30:
Im glad you worked it out. Apologies for not getting back to you!
You can also try double pressing the RESET button in quick succession.
Some of these Arduinos come with slightly different bootloaders and the exact process to get into the bootloader changes slightly.

Closed 2020-06-30.

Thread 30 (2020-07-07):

Multiple 8bitdo's Freezing

joshuaziel, 2020-07-07:
I'm looking to use multiple 8bitdo's by leveraging a USB hub connected to the single USB port on the OGX360.  I've paired two "gray" 8bitdo's with the "orange" firmware with two Xbox One wireless controllers and am able to use both controllers normally for a period of time.  However, after a few minutes of playing, one of the controllers ceases to provide input and "freezes" on whatever was last inputted.  Sometimes it occurs on Player 1, sometimes it occurs on Player 2.  For example, in a driving game, it could be constantly turning one driver to the left with the gas applied.  No other buttons are effective in resetting this.  The other player is not affected.  To fix, I need to unplug the physical controllers from OGX360 to the Xbox (removing power to all Arduino's) and then reconnect.  Any thoughts?

Ryzee119, 2020-07-08:
Thanks for raising the issue.
Its certainly a less tested use case.
Is your usb hub externally powered or powered by the ogx360?

If youre able to, could you try with an externally powered usb hub and let me know

joshuaziel, 2020-07-10:
I only have a few bus powered hubs but let me see if I can find a powered one to borrow.  Thank you.

joshuaziel, 2020-07-10:
I should note that I did try it one bus powered hub (AmazonBasics) and it wouldn't even power one 8bitdo.  I moved to an Aukey one and it seems be powering both 8bitodo's fine, save for this issue.  I have had no issues using either one 8bitdo plugging directly into the ogx360 (already a tested use case) nor plugging one 8bitdo into the Aukey bus powered hub and then plugging the hub into the ogx360.  How tight are the margins on the overall circuitry given all of this would have to fit within the Controller 1 power budget?

Ryzee119, 2020-07-14:
I wouldn't think powering all four 8bitdos would be an issue at all really.

This is an interesting problem, and unfortunately may come down to the limits of the atmega32u4s and possibly https://github.com/Ryzee119/ogx360/issues/7.

We may not be meeting timing requirements through the USB hub :(

joshuaziel, 2020-08-12:
I was able to procure an AC powered USB hub and have yet to experience the issue (hard to extensively test two players during quarantine!) so I would think you can close this with guidance to use externally powered hubs instead of bus powered.

Ryzee119, 2020-08-21:
Thank you for that testing :)
I will add a note to the README!

Ryzee119, 2020-08-21:
Added a note

Closed 2020-08-21.

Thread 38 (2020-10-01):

Mayflash adapters.

K-Hobert, 2020-10-01:
The Mayflash magic pro is a USB crossover adapter which supports x-input. Displays its self as a “Xbox 360 controller for windows”. The interest for myself is input usb on the adapter itself. Could be used to support more wired controllers that lack xinput and Bluetooth. Having tested the Bluetooth connectivity it worked seemly perfect. But using the device bugged out the board other wired controllers (on an externally) powered hub stopped receiving input to the console. Board has to be powered off but the Mayflash keep working....added the VID/PID into 360 support column.

K-Hobert, 2020-10-01:
Figured a work around, first plug the mayflash in first (synced to a wireless controller) then use a second controller as a dummy controller. Plug a 3rd controller in the 3rd acts as the playable second controller.

Ryzee119, 2020-10-01:
interesting work around!

Can you provide a USB descriptor dump of this deviec when connected into windows? Im wondering if it's a composite device and registering a 2nd slot but not sending outputs to it.

K-Hobert, 2020-10-06:
Information for device MAGIC-S PRO (VID=0x2F24 PID=0x00F7):

Connection Information:
------------------------------
Device current bus speed: FullSpeed
Device supports USB 1.1 specification
Device address: 0x0001
Current configuration value: 0x01
Number of open pipes: 2

Device Descriptor:
------------------------------
0x12	bLength
0x01	bDescriptorType
0x0200	bcdUSB
0xFF	bDeviceClass      (Vendor specific)
0xFF	bDeviceSubClass
0xFF	bDeviceProtocol
0x40	bMaxPacketSize0   (64 bytes)
0x2F24	idVendor
0x00F7	idProduct
0x0101	bcdDevice
0x01	iManufacturer   "."
0x02	iProduct        "MAGIC-S PRO"
0x03	iSerialNumber   "0243ED2700009D45"
0x01	bNumConfigurations

Configuration Descriptor:
------------------------------
0x09	bLength
0x02	bDescriptorType
0x0030	wTotalLength   (48 bytes)
0x01	bNumInterfaces
0x01	bConfigurationValue
0x00	iConfiguration
0x80	bmAttributes   (Bus-powered Device)
0xFA	bMaxPower      (500 mA)

Interface Descriptor:
------------------------------
0x09	bLength
0x04	bDescriptorType
0x00	bInterfaceNumber
0x00	bAlternateSetting
0x02	bNumEndPoints
0xFF	bInterfaceClass      (Vendor specific)
0x5D	bInterfaceSubClass
0x01	bInterfaceProtocol
0x00	iInterface

Unknown Descriptor:
------------------------------
0x10	bLength
0x21	bDescriptorType
Hex dump:
0x10 0x21 0x10 0x01 0x01 0x24 0x81 0x14 0x03 0x00
0x03 0x13 0x02 0x00 0x03 0x00

Endpoint Descriptor:
------------------------------
0x07	bLength
0x05	bDescriptorType
0x81	bEndpointAddress  (IN endpoint 1)
0x03	bmAttributes      (Transfer: Interrupt / Synch: None / Usage: Data)
0x0040	wMaxPacketSize    (1 x 64 bytes)
0x04	bInterval         (4 frames)

Endpoint Descriptor:
------------------------------
0x07	bLength
0x05	bDescriptorType
0x02	bEndpointAddress  (OUT endpoint 2)
0x03	bmAttributes      (Transfer: Interrupt / Synch: None / Usage: Data)
0x0040	wMaxPacketSize    (1 x 64 bytes)
0x08	bInterval         (8 frames)

Microsoft OS Descriptor:
------------------------------
0x12	bLength
0x03	bDescriptorType
Hex dump:
0x12 0x03 0x4D 0x00 0x53 0x00 0x46 0x00 0x54 0x00
0x31 0x00 0x30 0x00 0x30 0x00 0x90 0x00

String Descriptor Table
--------------------------------
Index  LANGID  String
0x00   0x0000  0x0409
0x01   0x0409  "."
0x02   0x0409  "MAGIC-S PRO"
0x03   0x0409  "0243ED2700009D45"

------------------------------

Connection path for device:
Intel(R) ICH10 Family USB Universal Host Controller - 3A36
Root Hub
MAGIC-S PRO (VID=0x2F24 PID=0x00F7) Port: 1

Running on: Windows 10 or greater (Build Version 18363)

Brought to you by TDD v2.15.0, Jun  8 2020, 17:18:07

K-Hobert, 2020-10-06:
With a device plugged in to Mayflash's USB port two changes happen in the descriptor
Current configuration value: 0x00
Number of open pipes: 0

Ryzee119, 2021-07-06:
Could you please retry this with latest v2.x firmware

Ryzee119, 2021-08-10:
Will close as stale. If issue is encounted on latest firmware please create a new issue

Closed 2021-08-10.

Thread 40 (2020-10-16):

8bitdo - Xbox One Controller issue

CrispyWhispy, 2020-10-16:
Hi there,

Just trying to get the ogx360 working with an Xbox One controller via 8bitdo.

The controller pairs with the 8bitdo, but doesn't seem to be passing commands.

8bitdo confirmed working with Nintendo Switch.
Controller works fine natively via Bluetooth to PC.

I have tried 8bitdo firmware versions-
1.26
1.27
1.28
1.30
1.33

The Xbox One controller firmware was well out of date when I started - ver. 3.x.xxxx.x
Now I've updated it to ver. 4.8.1923.0

Just followed your steps in the firmware section - https://github.com/Ryzee119/ogx360/tree/master/Firmware
and updated the Master board to your latest (v15) hex - ogx360_32u4_master.hex

Also, I assuming if I wanted to use the Xbox One controller as wired, I would just connect it via USB to the USB port the 8bitdo/Xbox360 wireless receiver would plug into? This still doesn't work though.

Unfortunately I do not have an Xbox360 wireless receiver to test my 360 controllers with the ogx360.

Edit- I found a reddit post - https://www.reddit.com/r/originalxbox/comments/i8n0yv/ogx360/
And I tried holding the Select + Up on D-Pad for at least 3 seconds after pairing to no avail.

Any help would be great. Thanks.

Ryzee119, 2020-12-08:
Hi apologies for the late response.
Do you get a second led appears on the master arduino when you plug in the 8bitdo adaptor?
Is it the orange unit and not the grey?
I am working on a separate branch on github here that may improve some of the packet reliability that could help. Should be done in a day or so

CrispyWhispy, 2020-12-09:
Hey, not a drama. I saw you had replied to other threads so I thought to just wait my turn haha.
Here's a photo, using the orange 8bitdo and red LED on the daughter board flashes on and off.
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

Ryzee119, 2020-12-09:
Have you got this working on any device at all?

Flash red led at a rate of 500ms off, 500ms on is a sign that it cannot initialise the MAX3421 🤔

CrispyWhispy, 2020-12-09:
Unfortunately I don't have an Xbox 360 wireless dongle if that's what you mean.
And the using a USB cable to put the controller in "wired mode" through the ogx won't work either.
The single Xbox One (bluetooth) controller that I know works connecting straight to PC, or via 8bitdo to Switch.

In this video below you can see the power up of the device, the 8bitdo gets power, syncs with the controller - no input accepted. The flashing is around 500ms I would say. What's the next step if the MAX3421 is the issue?
I press the 'RESET' button on the motherboard and the two daughterboard LEDs come on, with the originally flashing LED going solid for a few seconds, then flashing again - still no input.

https://drive.google.com/file/d/1s6TCYU2YNybFQvBiI2Hso1EIs-yx2N3j/view?usp=sharing

Ryzee119, 2020-12-09:
Unfortunately its normally a sign of something faulty. How proficient are you in fault finding?
Are you located in Aus?

CrispyWhispy, 2020-12-09:
That's a shame. Bought this unit from TEK Nemesis in Canada.
Pretty proficient from a general standpoint, I'm a Systems Engineer for an ISP by day (and night)....in this regard I suppose I could crack out the multimeter and probe away if you point me in the right direction.
Yeah I'm in QLD.

Ryzee119, 2020-12-09:
You could try this firmware.
Its just alot newer and had lots of changes. It may not may not help.
[MASTER_360WLESS_360W_STEELBATTALION.zip](https://github.com/Ryzee119/ogx360/files/5664868/MASTER_360WLESS_360W_STEELBATTALION.zip)

If thats no good, I have a bunch of spares here. I can shoot one youre way if youre happy to send me the dud?
Ive seen a few of these ones that fail with no apparent reason so I would be interested to try debug it.

CrispyWhispy, 2020-12-09:
Alrightly, happy to send it to you based on the outcome of this -

Just flashed that firmware
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

Now the daughterboard LED flashing every 10 seconds, still not accepting input

Ryzee119, 2020-12-09:
Sounds faulty. Hit me up at wendland@live.com.au to exchange info ill send one you're way.

Keep your case and cables etc.

CrispyWhispy, 2020-12-09:
Not a drama, just emailed you now. Many thanks.

Ryzee119, 2020-12-11:
Was this damn crystal
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

Closed 2021-01-01.

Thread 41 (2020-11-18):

Customized ogx360 hardware with Pro Micro 3.3V

phantom-8, 2020-11-18:
I've built a simplified version of ogx360 with a Pro Micro 3.3V/8MHz board and a Mini USB Host Shield 2.0.  It only supports 1 Xbox 360 controller.  Everything seems to work fine, except it missed a button release event once a while.  I suspect the culprit is the slower 8MHz of the Pro Micro.  Do you have any idea on how to tackle the problem?

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

Ryzee119, 2020-11-18:
Very nice!
It could certainly be an issue. As its limited to one controller you can try these:

Make this loop to 1 instead of 4 to avoid some overhead
https://github.com/Ryzee119/ogx360/blob/27942f1965dc4b0a7e773592d668ba88c2513541/Firmware/ogx360_32u4/main.cpp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

Have you adjusted `F_CPU` to match your new clock? Not sure how your compiling, but its a define setup in your project.

You could try bumping up the SPI speed. I think its set here (and look for other instances for 12000000 in that file. The default was originally 26000000.

https://github.com/Ryzee119/ogx360/blob/27942f1965dc4b0a7e773592d668ba88c2513541/Firmware/ogx360_32u4/lib/USB%20Host%20Shield/usbhost.h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

phantom-8, 2020-11-18:
Thank you so much for the prompt reply.  I've already removed unnecessary code in main.cpp.  At the moment, all I2C code are gone; the main "for loop" iterates only once; master's slave handling code are gone.  The F_CPU is already set to 8000000UL.  Unfortunately, the problem still exist.

I'm gonna try to play around with the SPI setClockSpeed and see if it helps.  Thanks again for your kind assistance.

phantom-8, 2020-11-18:
Just tested the SPI Clock.  In the ushhost.h, the ATMega32u4 doesn't use setClockSpeed.  Instead, the clock speed is being set via SPCR & SPSR registers.
```
78                 SPCR = 0x50; //SPI Enable and MASTER,
79                 SPSR = 0x00; // 0x01 = SPI2X Ryzee119, changed from 0x01 to 0x00 to disable SPI2X. Speed is fclk/4 now.
```
The SPI Clock is currently being set to 4MHz for Pro Micro 16MHz version, and 2MHz for Pro Micro 8MHz version.  I've bumped the clock speed to 4MH by setting SPSR=0x01.  The 4MHz SPI Clock is the maximum that can be set on the Pro Micro 8MHz version.  Unfortunately, this didn't fix the problem.

Can I ask how the MAX3421 handles controller button events?  Does it only send button change events via SPI (that is, only send 1 event for button down and another event for button up)?

Ryzee119, 2020-11-18:
ah yes ofcourse. been a while since Ive looked deep into this code.

MAX3421 generates an interrupt on all new events on the usb device. ogx360 polls this interrupt register to detect changes and applies them accordingly.

Most controllers will only send a new packet if a change has been detected. For example if you're moving the analog stick around do the missed button presses happen?

Im wondering if this section is happening *too quickly* and is clearing previous buttons before it can send it to the og xbox. ogxbox is capped as 4ms per interrupt packet. xbox 360 can do 1ms.

https://github.com/Ryzee119/ogx360/blob/27942f1965dc4b0a7e773592d668ba88c2513541/Firmware/ogx360_32u4/main.cpp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

Although counter intuitive, add a 4ms delay on each loop.

The 4ms thing is here. You could try changing the `>=4` to 0 or 1. Although I have had issues when im spamming the og too fast much. :)
https://github.com/Ryzee119/ogx360/blob/27942f1965dc4b0a7e773592d668ba88c2513541/Firmware/ogx360_32u4/main.cpp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

phantom-8, 2020-11-19:
> MAX3421 generates an interrupt on all new events on the usb device. ogx360 polls this interrupt register to detect changes and applies them accordingly.
>
Thanks for the explanation.

> Most controllers will only send a new packet if a change has been detected. For example if you're moving the analog stick around do the missed button presses happen?
>
Yes, if I moved the analog stick, the missed button press/release will be updated.

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
It seems to me your code is fine.  I don't think the problem is related to your button handling or the timing on sending HID report to OG.  My theory is that the 8MHz Pro Micro is only running at half speed, it's not fast enough to poll the interrupt register to capture all button change events.  I think the following are the possible ways to solve the problem:

1) Use a Pro Micro version with 3.3V/16MHz which are being sold on ebay & Aliexpress.  The ATMega32u4 will be running out of spec, but most people reports are positive.

2) The current implementation uses polling to process the button events.  This will be problematic for slower MPU.  A better way would be interrupt driven.  I think you mentioned to migrate to UHS3.0 in the future.

3) UsbHost.Task() is not being called fast enough and result in lost events.  Currently, it's being called once at the beginning of the main loop.  We can try to add 1 or more calls to UsbHost.Task() in the main loop and spread them evenly.

I will try approach 3 first and see if it helps.  If not, I think I may go with approach 1.

phantom-8, 2020-11-19:
Approach 3 didn't work as the problem is within UsbHost.Task().  The Poll() function makes calls to checkControllerPresence(), checkControllerBattery(), setLedRaw(), chatPadKeepAlive1() & chatPadKeepAlive2() every 2.5 seconds.  These functions will send commands to MAX3421 via SPI bus.  As long as I comment out all these functions, the system will run reliably and no more message lost.  If I leave any 1 of these functions intact, it will also result in message lost.  These functions create more traffic on the SPI bus and the 8MHz Pro Micro seems insufficient to handle it.  I guess my only option now is to use a Pro Micro version with 3.3V/16MHz.

https://github.com/Ryzee119/ogx360/blob/27942f1965dc4b0a7e773592d668ba88c2513541/Firmware/ogx360_32u4//lib/USB%20Host%20Shield/XBOXRECV.cpp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

jimnarey, 2020-11-24:
Hi Phantom8 - is there any chance you could share your simplified code? I was about to dive in and do something similar myself (so far using a Leonardo with a full sized shield).

Thanks.

Ryzee119, 2020-11-24:
https://github.com/Ryzee119/ogx360_t4
I knocked this up recently.
Which uses a single teensy4.1 that can do dual usb.
Its a huge jump in power and flash memory so opens up lots of possibilities for future work.

Ryzee119, 2020-11-24:
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

jimnarey, 2020-11-24:
And based in VS Code! Thank you so much for pointing me to this.

phantom-8, 2020-11-25:
I've built another version based on Pro Micro 5V/16MHz.  I used 5V to 3.3V logic convertors for SS, MOSI, SCLK & D9.  Basically, the circuit is the same as the one on your schematics.  Unfortunately, this version also encounters button lost events, exactly like the 3.3V/8MHz version.  I tried using both your Github compiled firmware and also my own built.  They've the same problem.  I'm really puzzled on what's going on.

@Ryzee119, is it possible for you to test whether your version has button lost events?  The way that I tested was using the Controller test tool from your Video.  I just keep pressing/releasing the same button and watch the controller screen for missing press/release.  In average, I would lose a button event every 100 button presses.
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
Ryzee119, 2020-12-04:
https://github.com/Ryzee119/ogx360/tree/xboxrecv/Firmware/ogx360_32u4
Try this branch. Needs to be burn tested will be interesting to see if this helps with the rare button press you are missing now

phantom-8, 2020-12-05:
In source file XBOXRECV.cpp, you've added the handling of 0x03 packet for button events, but you haven't handled 0x03 on the chatpad.  The 0x03 is a merged packet for controller & chatpad events.  I would suggest change line #373 to this in order to avoid missing chatpad events.

```
    }
    if(readBuf[0] == 0x00 && (readBuf[1] == 0x02 || readBuf[1] == 0x03)){
```

I'll preform testing in a moment.

Ryzee119, 2020-12-05:
the `0x03` packet I think only contains the chatpad led status, not chatpad button events from what I have seen, but I could be wrong though

phantom-8, 2020-12-05:
It's most likely the Controller firmware merged button & chatpad events due to traffic concern.  If 0x03 can contain chatpad LED events, it's very likely it may also contain chatpad buttons.

Ryzee119, 2020-12-05:
yep looks like youre right :) Ill push a new change shortly

Ryzee119, 2020-12-05:
Alright, ive push those changes. Disclaimer havent tested them myself

phantom-8, 2020-12-05:
Will test the latest update now.

Ryzee119, 2020-12-05:
sorry, just found another small bug which I have fixed related to chatpad returning incorrect buttons if you mashed multiple buttons quick enough  👍
Pushed that too.

Nice this seems to be working alot better now

phantom-8, 2020-12-05:
No problem.  Will fetch the update.  :)

phantom-8, 2020-12-05:
Time for test report, here are the findings:

1) When pressing the Guide button on the controller to connect to the wireless receiver, they sync up perfectly every time.  However, the controller number LED indicator sometimes keeps flashing (4 ring LEDs keep flashing) without settling to show the controller number.  To reproduce, press Guide to connect.  Then, press and hold Guide for a few seconds to disconnect.  I’ve repeatedly tested 10 times, 4 out of 10 will just keep flashing.  Other 6 times successfully settled to show controller number LED.  BY THE WAY, I’ve re-tested the original firmware before these code changes, this problem wasn’t there.

2) With the stock firmware, that is checkStatusTimer at 2500ms, I’m unable to reproduce button lost.  PERFECT!!!

3) Modified firmware with checkStatusTimer at 10ms and only calls to checkPadKeepAliveN(), no lost button event detected!

4) Modified firmware with checkStatusTimer at 10ms and only calls to checkControllerPresence(), lost button event occurred with button bashing.  With the attached log file, at time 00:00:15:183, controller button A press was deteced.  But no button release event was deteced afterwards.

The checkControllerPresece() still results in lost message under extreme condition with 10ms calling interval.  However, I’m unable to reproduce it under normal condition with statusStatusTimer at 2500ms.  I believe it will be very difficult to encounter under normal usage.

Test report for test#4 can be download here:
https://drive.google.com/file/d/1CJuaxPktqSTsD7N0J8CRyJ8JSVkMuBa_/view?usp=sharing

Ryzee119, 2020-12-05:
Once again, thank for you for the thorough testing.
I have push some more changes to hopefully fix that LED issue. These wireless controllers are very picky 👍

The simply the act of logging is very slow may be causing more missed events than without logging.  But I think at this point there's not too much else we can do without alot of rewrite. We're at an acceptable level now I hope.

phantom-8, 2020-12-05:
I've retest the LED issue, it's now fixed.

For test case #4, I first tested without logging.  When problem occurred, I turned on logging (by adding the logging code 'cos it wasn't in the latest source version).  Then, I re-tested again and collected the log, so I can see what exactly was going on.  Therefore, the problem was not resulted from the addition of logging code.

Anyway, I fully agree with you.  The current version is very good and I wouldn't worry about the possibility of checkControllerPresence() causing missing button events.  In fact, I wasn't able to reproduce the problem under normal 2500ms timing.

Again, thank you very much for your excellent work and the help to solving these issues.

Ryzee119, 2020-12-05:
No problem ☺ checkControllerPresence() may even be optional. Could just remove it too

phantom-8, 2020-12-05:
If it can be removed, it will be perfect!  Anyway, I'm extremely happy with the current version.  It's your call whether you still want to try removing it.

I've just received the 3.3V/16MHz Pro Micro.  I'll test it later and see if it's stable.  I'll also re-test the 3.3V/8MHz version and see if it's fast
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

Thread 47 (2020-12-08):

Help: "MAX3421 Revision invalid" in debug program

itsmattkc, 2020-12-08:
Sorry if this isn't the right place for this, I wasn't sure where else to post it.

So I've been trying to build one of these myself and keep running into the same issue printed by the debug program:

```
MAX3421 Revision invalid. Value returned: 00
Unrecoverable error - test halted!!
0x55 pattern is transmitted via SPI
Press RESET to restart test
```

I've built two of these so far and both show this error. My first build actually returns `FF` instead of `00` if that's relevant, but the rest is identical. I'm also using the same Arduino between the two at the moment (they're socketed).

I assumed I must not have soldered the MAX3421 correctly, but through numerous attempts of reflowing all the pins, I've never been able to get past this message.

Is there something else I should be checking or is the MAX3421 soldering job the only real culprit?

chaddoncooper, 2020-12-08:
Would check the soldering on the voltage regulator and that the chip is getting power.

Ryzee119, 2020-12-08:
That SMD crystal is often an issue and can cause the symptom you're seeing.
As mentioned, check all power rails. Make sure that buffer under the 1st arduino is getting power etc.

itsmattkc, 2020-12-09:
Hmm still much the same. I've reflowed pretty much everything (including the crystal), I've confirmed with a multimeter that the regulator is producing 3.3V, and the USB controller and buffer are both getting that 3.3V at their VCC pin.

Only thing I haven't tested is another Arduino, but feels like that's next on the list?

Ryzee119, 2020-12-11:
What happens when you use the standard ogx360 firmware? Does the led flash?

Ryzee119, 2020-12-11:
That being said, invalid revision seems like an issue on the SPI bus.
If you have access to a oscilloscope check the MISO, MOSI, SCK and CS lines on the arduino to see if you get traffic on all of them.
Also try this firmware: It significantly slows down the SPI speed to eliminate SPI speed being an issue
https://github.com/Ryzee119/ogx360/files/5664868/MASTER_360WLESS_360W_STEELBATTALION.zip

itsmattkc, 2020-12-11:
Yes, the LED flashes in normal mode.

I'm afraid I don't have an oscilloscope (probably something worth getting one day though)

I'll try that firmware now and see what happens.

Ryzee119, 2020-12-11:
What 12mhz crystal are you using? From digikey or somewhere else?

itsmattkc, 2020-12-12:
So funnily enough it's not flashing anymore. Same error but no flash, I'm not sure if that's good or bad.

Yep same crystal from digikey listed in the files: https://www.digikey.com.au/product-detail/en/ECS-120-12-30B-AGM-TR/XC2676CT-ND

Slow firmware doesn't make a difference unfortunately.

Still waiting for a second Arduino to arrive so I can test that.

itsmattkc, 2020-12-15:
Unfortunately same story with a second Arduino.

Does anything look wrong on my board?
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

Ryzee119, 2020-12-15:
Must be SPI comms issue or MAX chip not booting or held in reset or something.
Check these points
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

itsmattkc, 2020-12-15:
Ahhhh I finally got it. Such a silly mistake. A few of the buffer pins indeed weren't soldered correctly. Despite thinking I'd reflowed the whole thing a few times, I guess the solder just didn't get in there (the socket header made accessing it tricky which definitely didn't help).

I'm so sorry to have wasted your time. It works great now, thank you so much for the help and for making such a cool project.

Closed 2020-12-15.

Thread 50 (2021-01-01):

Populated boards

AireagoirSteam, 2021-01-01:
More of a suggestion really.
I was wondering if Gerber files could be added for populated boards or isnt that possable?

Ryzee119, 2021-01-01:
Im not sure I understand what you mean.
Gerbers are a format that describes the placement of copper, holes, silk screen and component footprints etc.

Populated boards must be made in conjunction with the materials list or working with a pcb fabricator to solder the parts for you.

AireagoirSteam, 2021-01-01:
Thank you for the fast reply I remember another project on here a cartridge reader had a way of ordering populated PCB thought it was to do with the Gerber files.

Which I'd why I suggested it.

Ryzee119, 2021-01-01:
I have a new branch that has reworked the PCB and will use kitspace as a ordering system.
Its much simpler just a few clicks to order the boards and components

This will still need self assembly though.

If you want pre assembled boards theres a few sellers out there.

Here for example
https://www.facebook.com/groups/TheMODShopByTEK/?ref=share

Closed 2021-01-01.

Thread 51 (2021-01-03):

Soft and hard presses aren't registering in games using 8bitdo and Xbox One Controller Model 1708.

regulardude400, 2021-01-03:
### Firmware versions:
Xbox One Controller Player 1 Firmware version via Xbox Accessories App: 4.8.1923.0
Xbox One Controller Player 2  Firmware version via Xbox Accessories App: 3.1.1221.0

All 8BitDo adapters are running firmware 1.33 using the tool located [here](https://download.8bitdo.com/Firmware/Receiver/usb_adapter/8BitDo_USB_RR_Firmware_V1.33.zip)
OGX360 is running firmware 1.5 ogx360_32u4_master.hex72.1 located [here](https://github.com/Ryzee119/ogx360/releases/tag/V1.5)

### USB Descriptors for 8BitDo Adapters:
8BitDo Adapter for [Player 1]( https://pastebin.com/6iKtNPYy)
8BitDo Adapter for [Player 2](https://pastebin.com/ubBH29EA)

### Problem Description
Hi not sure if this is controller related but I have 3 Xbox One controllers that are all Model 1708.  I am using the following setup with my Xbox. 4 Xbox One Controller (Model 1708) -> 4 8BitDo Red Bluetooth Adapters -> Powered USB Hub -> OGX360 -> Xbox.

When playing games like Dead or Alive 3, you can see which input are you pressing. I discovered that with the original Xbox controller model s, it registers soft presses and hard presses as two distinct button press types.  When I plug in any of my Xbox One Controller Model 1708, it can only register the controller as soft input only or hard input only. What causes the device to register one over the other is still unknown to me. But it seems that OGX360 is not recognizing soft input and hard input when it comes to games like Dead or Alive 3.  I have linked a Youtube video to this to hopefully better explain the problem. Excuse the dust and distracting noises that you may see or hear in the [video](https://youtu.be/hre9fE_iuiA)

Ryzee119, 2021-01-03:
Xbox one controllers do not have pressure sensitive buttons like the original controller.

This is a known issue. The buttons are either fully on or fully off.

Why it sometimes registers soft presses im not sure. Id expect hard presses all the time

regulardude400, 2021-01-04:
Hey just want to say thanks for all of the hardwork you do and that I appreciate your response on this known issue. I didn't look at all of the source code yet, but I guess the buttons are enums. If this is true, would it be feasible to add a button combo for ogx360, like for example: Press select + L + B to switch to soft input mode and hit that same combo again to switch to hard input. I'm not sure how the original xbox even reads soft and hard presses. But if my premise is true in any way, it may be a simple hotfix to work around the issue. Thanks again for your time.

Ryzee119, 2021-01-04:
I should be able to do that no problem. Ill look onto it as soon as i can

regulardude400, 2021-01-09:
I think it is okay to close this issue if you wish Ryzee.  A workaround for this is to disable analog button in the options menu if the game supports this particular setting.  I'm not sure if DOA 2 Ultimate and DOA 3 are the only games to use analog input in this manner but should help others get around the issue hopefully. Thanks again for your time.
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

Ryzee119, 2021-01-09:
oh awesome. Glad there's an option.
Ill close the issue but for reference this section of code sets 0xFF(max) or 0x00(min) for the analog buttons. Changing the 0xFF will change the button press intensity. a modifier button or timer thing could be implemented if anyone requires this feature.

https://github.com/Ryzee119/ogx360/blob/73a1a9be35e1146757e6c1803a8bf36d2acedd24/Firmware/src/main.cpp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

Closed 2021-01-09.

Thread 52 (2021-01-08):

Button Remaping?

Nashismo, 2021-01-08:
Hi Dear Ryzee!

I bought from you one of these adapters! One of the frist prototypes! I am the chilean guy from the OGXbox forum :)

I wanted to ask you, maybe in the latest firmware you already added button remaping? Mostly what I would love to have is the ability to remap the right analogue joystick! Mostly for games like Bad Fur Day and Ninja Gaiden Black, that have inverted cameras, which sucks because games today have us used to non inverted cameras.

Do you have something like that implemented already? Sorry to bother you with such a thing!

Thank you so much,
Nashismo

Ryzee119, 2021-01-09:
See https://github.com/Ryzee119/ogx360/releases/tag/V1.61
You can now toggle the Yaxis on the right stick by holding the Right stick in then pressing BACK..

Please let me know how this goes :)

Nashismo, 2021-01-10:
I cannot believe this! You really did this? You are amazing, I will be checking tomorrow, because tomorrow I will have some free time. I will be telling you if everything works fine.

You are a sun Ryzee! :)

Nashismo, 2021-01-12:
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

Dear Ryzee, after some trial en error I finally flashed the firmware correctly, and I got my wirleless 360 controller working great. Sadly, the new feature does not work for me. I flashed the 1.61 firmware but to no avail.

At least in Ninja Gaiden Black it is not working, I press the right joystick stick in, then back, but nothing happens. I have both an original wireless 360 controller and an original microsoft USB wireless receiver.

At least I learned how to update the firmware!

Thank you still Ryzee, maybe when you have time you can take a look at this. Thank again for everything,

Nashismo

Nashismo, 2021-01-12:
NOOOOOO I checked again and sure!! It works! But it is the horizontal axis which needs fixing! The Y axis changes but that is not the problem, it is the X axis the one that is backwards in many games dear Ryzee!

My best regards Ryzee! I hope you can understand what I mean ;)

Ryzee119, 2021-01-13:
Ah right my bad
If you can compile yourself its as easy as changing this section. Replace rightStickY and rightStickY with X.
https://github.com/Ryzee119/ogx360/blob/3c8cdbdc67dfb97554b2dc584dbefda3d08c103b/Firmware/src/main.cpp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

Nashismo, 2021-01-13:
Dear Ryzee, I did it exactly as you told me to:
     XboxOGDuke[i].rightStickX = -getAnalogHat(RightHatX, i) - 1;
 else
     XboxOGDuke[i].rightStickX = getAnalogHat(RightHatX, i);

 it compiled fine and it works as intended...

But now the Y axis is not working at all! :( I cannot look up and down, etc.

Forgive me Ryzee for bothering you. I didn't change anything else in the code, only those 4 instances where I replaced Y for X.

Cheers and thank you so much for your time Ryzee

Nashismo, 2021-01-13:
I fixed it myself! There was a line missing in the code:

//Read Control Sticks (16bit signed short)
                    XboxOGDuke[i].leftStickX = getAnalogHat(LeftHatX, i);
                    XboxOGDuke[i].leftStickY = getAnalogHat(LeftHatY, i);
                    XboxOGDuke[i].rightStickX = getAnalogHat(RightHatX, i);
                    XboxOGDuke[i].rightStickY = getAnalogHat(RightHatY, i);     (this one)

After I changed that and recompiled the firmware, everything worked as intended!! Thank you Ryzee

Ryzee119, 2021-01-14:
ah yep youre right, I we needed to add that time back in!
Glad you got it going!

Closed 2021-01-14.

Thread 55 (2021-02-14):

V1.61 Y axis toggle mode does not function

jfoshee900lbs, 2021-02-14:
I just flashed the latest version through the VS code method to try the Y axis toggle mode. For me the right stick just gets disabled and no longer responds.

I am using an 8bitdo wireless receiver on firmware v2.0 hooked directly into a full OG x360 kit with only the master arduino hooked to the p1 port of the xbox. I have tried with both an Xbox one controller, and a PS5 controller, both just cause the right stick to no longer function when the mode is toggled.

The rest of the controller operates as intended, only the right stick is affected.

Also I'll use this moment for a feature request for a hotkey to flip the X axis on the right stick as some games also get that wrong and don't have an option.

Thanks!!

jfoshee900lbs, 2021-02-14:
Goodness I'm sorry, it takes a full minute to make the switch. completely works as intended. My mistake

Ryzee119, 2021-02-14:
It should switch instantly so thats interesting its taking so long.

X-axis isnt implemented at the moment. I can look into it though

Closed 2021-02-14.

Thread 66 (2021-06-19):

JLCPCB assembly?

CoolOppo, 2021-06-19:
Hi! I would really like to just order a fully assembled PCB version from you, even if it's more expensive than doing it myself, to support the project, but (understandably) it doesn't look like it's something you offer. The next best thing for me would be to just get it fully assembled by JLCPCB. As you may or may not know, JLCPCB has support for submitting a couple extra files, and having them fully assemble an uploaded board. Are the files here compatible with this?

Some recommended (by me) links for ease:

[YouTube video showing how to prepare KiCad files for assembly from JLCPCB](https://www.youtube.com/watch?v=VejO8rDdhzo) (awesome vid, I've watched it all the way through)
[Official link from JLCPCB for how to get assembly services with KiCad](https://support.jlcpcb.com/article/84-how-to-generate-the-bom-and-centroid-file-from-kicad)

This could also be something you could use to get a bunch ordered so you can send them out to people! If you had some pre-assembled versions, I would _easily_ have bought one for like $60, and I bet you could get them for way, way less than that from JLCPCB, fully assembled, so just something to consider maybe!

Ryzee119, 2021-06-19:
Thanks for the suggestion! Also appreciate your support of the project.

Im familiar with jlpcb services but currently don't plan on making/selling more at this stage.

The easiest way to order them is via kitspace https://kitspace.org/boards/github.com/ryzee119/ogx360/

Just a few clicks and you're on your way but requires self assembly. There's quite a few sellers around who have supported the project in one way or other too if you just want fully assembled 😊

Closed 2021-06-20.

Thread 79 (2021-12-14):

8bitdo adapter 2

25glitch, 2021-12-14:
Just got 8bitdo adapter 2 stick adapter 1 not responding to Xbox series x controller on ogx360 and 8bitdo adapter 2 won’t stay powered on anyone have a solution to this

Ryzee119, 2021-12-14:
Thanks, im aware of this issue but do not have this new adaptor to test.

Could you please:
1. Provide a usb descriptor dump of the device. On windows I use this https://www.thesycon.de/eng/usb_descriptordumper.shtml
2. Ideally use wireshark to get a enumeration log from Windows which I assume it works in Windows

25glitch, 2021-12-14:
Information for device IDLE (VID=0x2DC8 PID=0x3107):

------------------------------
Connection Information:
------------------------------
Device current bus speed: FullSpeed
Device supports USB 1.1 specification
Device supports USB 2.0 specification
Device address: 0x001D
Current configuration value: 0x01
Number of open pipes: 2

------------------------------
Device Descriptor:
------------------------------
0x12	bLength
0x01	bDescriptorType
0x0110	bcdUSB
0x00	bDeviceClass
0x00	bDeviceSubClass
0x00	bDeviceProtocol
0x40	bMaxPacketSize0   (64 bytes)
0x2DC8	idVendor
0x3107	idProduct
0x0200	bcdDevice
0x01	iManufacturer   "8BitDo"
0x02	iProduct        "IDLE"
0x03	iSerialNumber   "E417D89BB8E9"
0x01	bNumConfigurations

-------------------------
Configuration Descriptor:
-------------------------
0x09	bLength
0x02	bDescriptorType
0x0029	wTotalLength   (41 bytes)
0x01	bNumInterfaces
0x01	bConfigurationValue
0x00	iConfiguration
0x80	bmAttributes   (Bus-powered Device)
0xFA	bMaxPower      (500 mA)

Interface Descriptor:
------------------------------
0x09	bLength
0x04	bDescriptorType
0x00	bInterfaceNumber
0x00	bAlternateSetting
0x02	bNumEndPoints
0x03	bInterfaceClass      (Human Interface Device Class)
0x00	bInterfaceSubClass
0x00	bInterfaceProtocol
0x00	iInterface

HID Descriptor:
------------------------------
0x09	bLength
0x21	bDescriptorType
0x0110	bcdHID
0x00	bCountryCode
0x01	bNumDescriptors
0x22	bDescriptorType   (Report descriptor)
0x0025	bDescriptorLength

Endpoint Descriptor:
------------------------------

25glitch, 2021-12-14:
Endpoint Descriptor:
------------------------------
0x07	bLength
0x05	bDescriptorType
0x02	bEndpointAddress  (OUT endpoint 2)
0x03	bmAttributes      (Transfer: Interrupt / Synch: None / Usage: Data)
0x0040	wMaxPacketSize    (1 x 64 bytes)
0x08	bInterval         (8 frames)

Microsoft OS Descriptor is not available. Error code: 0x0000001F

--------------------------------
String Descriptor Table
--------------------------------
Index  LANGID  String
0x00   0x0000  0x0409
0x01   0x0409  "8BitDo"
0x02   0x0409  "IDLE"
0x03   0x0409  "E417D89BB8E9"

------------------------------

Connection path for device:
USB xHCI Compliant Host Controller
Root Hub
Generic USB Hub
IDLE (VID=0x2DC8 PID=0x3107) Port: 3

Running on: Windows 10 or greater (Build Version 19043)

Brought to you by TDD v2.17.0, Feb 23 2021, 14:04:02

25glitch, 2021-12-14:
Endpoint Descriptor:
------------------------------
0x07	bLength
0x05	bDescriptorType
0x81	bEndpointAddress  (IN endpoint 1)
0x03	bmAttributes      (Transfer: Interrupt / Synch: None / Usage: Data)
0x0040	wMaxPacketSize    (1 x 64 bytes)
0x08	bInterval         (8 frames)

Ryzee119, 2021-12-15:
Thanks, I think there's something tricky going on here. Does it eventually appear as a xbox controller in Windows?

`0x02 iProduct "IDLE"` is weird. It probably is looking for some commands to get it going at startup.

I need to try grab one, but its sold  out by the looks of it

25glitch, 2021-12-15:
it's on amazon got one two days ago

25glitch, 2021-12-15:
it might have something to do with microsoft switching to from Classic to BLE bluetooth last september

Ryzee119, 2021-12-15:
@25glitch glad you got one but theyre sold out now

So this will be on hold until they're back in for me unless someone else investigates it further

CaptMoore, 2021-12-22:
If it matters, they are available on amazon again. I just ordered one for 2 day delivery.

Thanks for looking into it.

Ryzee119, 2021-12-22:
@CaptMoore thanks for the heads up
Ive ordered but im in Australia so prob a few weeks away

Ryzee119, 2022-01-12:
Ive got my 8bitdo receiver now and can replicate this issue. I'll investigate asap to see if we can get it going

Ryzee119, 2022-01-13:
Progress. Still needs a bit of love, but I worked out what it's doing.
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

Ryzee119, 2022-01-15:
[firmware 9aee4cd.zip](https://github.com/Ryzee119/ogx360/files/7874156/firmware.9aee4cd.zip)
Please try this firmware. Depending how old your firmware is (not updated since ~june 2021)  you may need to update all arduino modules.

CaptMoore, 2022-01-15:
Thanks, I am going to go out of town tomorrow for a week, but can check it after I get back.  I am sure others will be able to check it first.

Ryzee119, 2022-01-15:
From what I can tell, if the blue LED on the 8bitdo adaptor blinks twice every second or so, its initialised ok and looking for a previously paired controller.
If the LED stops blinking, ive done something wrong.

Just pair a controller as per normal and once a controller is paired and connected the LED goes solid and we're in business.

Ryzee119, 2022-02-22:
Closing. This has been merged into master branch. and got feedback from a couple people that this is working.

CaptMoore, 2022-02-22:
Thanks. Life has gotten in the way of testing this myself, and the task of flashing the ogx via command lines is pretty daunting (but I have done it before) so I never tried to run the beta firmware. I am looking forward to updating this when life lets me.

senolfeldmann, 2022-06-11:
This issue is present on firmware 2.15. The 8bitdo adapter 2 shuts itself off or does not receive power after ~1-2 seconds when plugged in directly into the ogx360s USB-A socket (only blinks shortly two times). The red led of the master arduino does not light up, too.
The behavior should be like with the 8bitdo adapter 1: The led of the adapter blinks shortly two times, pause, blinks shortly two times, pause, etc... until you press the sync button or connect an already synced controller. Additionally, the red light of the master arduino indicating a connected device lights up.
Strangely, the 8btido adapter 2 works as it should when I do not plug it in directly, but use a usb 2.0 extension cord in between.

Ryzee119, 2022-06-11:
I may need to revisit to see something has changed 🤔

Ryzee119, 2022-07-12:
Looks like

Ryzee119, 2022-07-12:
Looks like the FW update to 1.1 broke something. Feedback is that it still works on 1.0 FW which is easy to downgrade to.
Ive tried to fix it but not had much luck yet

25glitch, 2022-07-12:
I’m thinking the board may have to be rebuilt from scratch to accommodate the power requirements for the adapter 2

Dempsey86, 2022-07-17:
> Looks like the 8bitdo FW update to 1.1 broke something. Feedback is that it still works on the 8bitdo 1.0 FW which is easy to downgrade to.
> Ive tried to fix it but not had much luck yet

I do confirm this, now they ship new with v1.01 and there is a update to v1.02 (doesn't work). Reverted the FW to v1.0 and the stick works.

dleer, 2023-04-15:
I bought the 8bitdo adapter 2 last week and also just got an ogx360 mini. They seem to work perfectly together. I played some games for a few hours without issue using a 2020 model Xbox One controller.

There is one little quirk in that the 8bitdo won't automatically reconnect to the gamepad on power up of the Xbox. I have to press the 8bitdo's power button and then it connects. On a Windows PC the adapter does automatically connect.  I updated the firmware of the 8bitdo to the most recent but the behavior with the ogx360 is the same.

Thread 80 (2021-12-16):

Firmware updater GUI

Ryzee119, 2021-12-16:
Alot of users have issues updating the device. Its not too hard, but for a non technical user its probably not ideal.

We could have a GUI that prompts the user what to do and update the firmware.

CaptMoore, 2021-12-22:
I am not terrible with technology, but a simple firmware update app would be much appreciated.  I accomplished the update, but I had to try it a few times until I did it correctly.

If it’s not too much to ask, after a windows app is developed could there also be a macOS & Linux version?

Ryzee119, 2022-01-15:
`If it’s not too much to ask, after a windows app is developed could there also be a macOS & Linux version?`
Yes this would be ideal. Something Python based may be the easiest

dtomcat, 2022-07-18:
I just seen this... and I may be able to help...    No promises (GUI is not my cup of tea), but I'll attempt this and hopefully get it functional, then someone else can make a "pretty" GUI.   again no promises, but I'll look into it after I finish the automated OpenXenium programmer.

dtomcat, 2022-07-18:
and sorry... I would only be able to Windows... I'm no bueno with MAC/Linux

dtomcat, 2022-07-18:
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
 Progress!!..  Got a lot of it done... still needs work... but I say it went from 15% chance of being done... to 98%!

dtomcat, 2022-07-19:
Doing a lot of error checking (i.e. more than one pro micro connected... more than one pro micro put into programming mode at same time, etc).   Do you think we should add checksums to ensure user doesn't try to upload a correct hex file?  This would add a little more to your plate... with each firmware update, you'd need to add current build to file of checksums to validate against?  I'm going to make this as user friendly and as hard to screw up as possible.  I'm even checking for legit pro micros vs clones (still allowing to upload firmware, but in case an issue arises in future, we can tell if it's only clones, etc).

Ryzee119, 2022-07-19:
I wouldn't worry about checksum checking. Avrdude will verify the flash normally and as you say it would be a bit tricky to manage all the different checksums

dtomcat, 2022-07-19:
[Sneak Peak!](https://www.youtube.com/watch?v=kPFs9sGHJw8)

dtomcat, 2022-07-21:
@Ryzee119 mind testing first Alpha?  basically as seen in sneak peak...  this mostly just check that it will work on a PC that isn't mine
[OGX360 Firmware Updater.zip](https://github.com/Ryzee119/ogx360/files/9155769/OGX360.Firmware.Updater.zip)
.

Ryzee119, 2022-07-21:
Yep can do in the next day or so. Good work so far and definitely will help alot of users. Do you have source code on github anywhere?

Do you plan to opensource this and what license?

dtomcat, 2022-07-21:
Not yet.  It’s a bunch of ideas thrown together with no rhyme or reason.  Once I get a good beta… I’ll clean up the code and document and post to GitHub.   Will definitely be open sourced and have no clue on license.  Not familiar with them. I usually just post the code. Maybe someone can help me with which license I should do and how?

dtomcat, 2022-07-21:
Ok... a working initial Alpha version:
[OGX360 Firmware Updater.zip](https://github.com/Ryzee119/ogx360/files/9157520/OGX360.Firmware.Updater.zip)

Fingers Crossed!

Ryzee119, 2022-07-21:
I tried it out, and am hitting avrdude.exe: ser_open(): can't open device "\\.\COM5": Access is denied, but weirdly it programs find if I just run avrdude from the commandline separately.

I have a couple suggestions for your consideration

* Make the text "Firmware:" a hyperlink to the github release page
* Make "avrdude.exe" a hyperlink to the avrdude download page, also libusb0.dll
* I initially didnt have libusb0.dll in my folder which altered me perfectly, however after adding it in I had to close and reopen the program for it to find it. Maybe a rescan button or something could be useful.
* After clicking "Ready?" This window popped up as expected however the write button was hidden and I had to expand the window to see it. I had to watch your video above to work it out. Hopefully this can be fixed.
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

EDIT: It just started working :)
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

dtomcat, 2022-07-21:
Thank you for the feedback!  I believe the com5 issue at first would have been that the Pro micro timed out.  i've noticed that you only have a few seconds to initiate an upload before the pro micro resets out of programming mode.  (I'll add a note about this in the text).  I tried to create hyperlinks to no avail (i'll continue trying).  Did you get a splash screen initially telling you the requirements?  I had an issue after adding an icon... so I'm wondering is the issue wasn't from the icon ... I had a label disappear...  like you had the write button hidden...   not sure why that is... I'll try to reproduce that.  A rescan mechanism is definitely in the works!   that is weird... not sure why it didn't expand all the way... as you see in the video, it does on mine.  something I'll have to look into as well.  Thanks again for the feedback... long road ahead... but mostly cosmetic!  Main purpose of app is funtional

dtomcat, 2022-07-21:
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
Solutions....   Thoughts?

dtomcat, 2022-07-21:
@Ryzee119     another build  (has a debug function)... when the window resizes, and you have to manual make it bigger...   a windows will pop up with width/height ... can you send me those numbers?
1. barely resize it (like one pixel)  copy numbers
2. Resize it to make it look like video and copy those numbers

Thanks!  New features above are also incorporated
[OGX360 Firmware Updater.zip](https://github.com/Ryzee119/ogx360/files/9158488/OGX360.Firmware.Updater.zip)

dtomcat, 2022-08-26:
Just programmed 25 chips easily, zero errors, and quickly!  I think the functionality is spot on and ready… just need to work on the cosmetics.
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

dtomcat, 2022-09-25:
Just tried the program on my ogx360i-4ch boards I made... worked perfectly!  I'm confident that all that needs addressing is cosmetic issues. (at least on my PC).

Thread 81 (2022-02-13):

ogx360 can't start Steel Battalion

hpx1984, 2022-02-13:
Dear Sir Ryzee119

i'm used USB Host board and 3.3v/8M pro-micro board(first time i use 5v/16M but it can't working) for build a ogx360 and it can worked for xbox360 pc wireless receiver and 8bitdo wireless receiver
the FW is use this one
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

now  i can't start Game of Steel Battalion, is it means this FW can not support the key map of Steel battalion,
how i can fix my ogx360 board for support Steel battalion
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

by the way in your OGX360 Project's Pro micro board is 5v/16Mhz ,right?

many thanks your support sir

Ryzee119, 2022-02-13:
Get the latest fw from this github page.
Edit platformio.ini and change the 16mhz numbers to 8mhz and recompile and program

Ryzee119, 2022-02-23:
Did you have any luck with the latest firmware?

hpx1984, 2022-02-24:
Dear Sir Ryzee119

i had download the latest firmware in your project and i know how to change 16mhz to 8mhz in ini file
and i also downloaded and installed Arduino tool in my PC but i don't know how to recompile to HEX file
I may study how to use Arduino later
or could you help for recompile a 8mhz HEX?

hpx1984, 2022-03-13:
Dear Sir Ryzee119

i followed this guide try for compile a 8Mhz FW (i compile 16Mhz original FW first )
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

but got many error reported
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

i will try to study on Visual Studio Code usage hope can know how to fix the problem

hpx1984, 2022-03-13:
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

hpx1984, 2022-03-28:
Dear Sir Ryzee119

could you add one more FW version of 8Mhz in your next FW update release
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

now this FW can support PS3 controller so i think it also has possible for support PS3 Move controller for light gun play with House of the Dead , and I think the FW also is big challenge

Ryzee119, 2022-07-12:
8Mhz wont be officially support by me as I am unable to test it properly and cant comment on the impact of it.

Not finding Arduino.h header is not related and likely due to not cloning the repo properly.

Closed 2022-07-12.

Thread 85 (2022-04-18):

user issue flashing firmware

Talamis, 2022-04-18:
it flashes the firmware onto the new pro-micros with different brands
but it doesnt want to be recognized by the controller/xbox

the old one i flashed quite a while ago works on the new board flawless

Ryzee119, 2022-07-12:
Any update on this?  Could you provide more info like what brands etc.

wiredopposite, 2022-08-25:
I think I've had this issue as well, I managed to brick an Arduino I was using as a test unit. I had the debug hex programmed to it, then I programmed it again with Avrdude with the normal v2.15 fw (might have been the problem.) The wireless adapter would turn off when I tried to sync it, so I used Avrdude to flash back to debug but when I tried to use Termite, it switched modes/COM number on its own and can't be seen. VS code also won't program it, it'll start but when but I get to the point where you need to press reset, it doesn't do anything and just fails. I tried uninstalling in Device Manager and plugging it back in but after that it didn't even get detected anymore unless it was in bootloader mode.

Ryzee119, 2022-08-26:
TZT ones are normally fine. Ogx360 has to disable the standard arduino usb interface which is used for programming  for it to work.

The button on the board has to be used reload into the bootloader but it can be a bit tricky to time.

Sometimes you have to double press or hold and release when its about to program.
But I mean it's not possible for just this software to 'brick' it completely.

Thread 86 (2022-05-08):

ogx360 doesn't working ,need help

hpx1984, 2022-05-08:
Dear Sir

i had build 2sets ogx360 but all can't working
i used pro micro board 5v/16Mhz, test 2.0 and 2.1 FW , got same issue
when i plug ogx360 into xbox the green led turn on , i plug xbox360 controller or 8bitdo receiver into ogx360
the xbox360 controller LED flash two times and then turn off, 360 controller doesn't working

i checked the soldering workmanship and i didn't find any defect
USB vcc is 4.8v
can any one help for comment where i can check or verify
please help me

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

Ryzee119, 2022-05-08:
What value are the caps on the crystal? C2 and c3?

Alot of components look like substitutes so not sure if they are all suitable

hpx1984, 2022-05-08:
Hi sir

it is 16p , but i Measured it actual it is 15p

i have some 0603 size's cap and resistor on hand ,the value is match the bom request so i use then
i try to buy 0805 component for replace these 0603 components

hpx1984, 2022-05-13:
Hi Sir

now i used 0805 chip component for builded 3sets ogx360 still got same issue , the pro micro board just green LED on when i plug xbox360 wire controller into USB connector and the controller just flash two times LED on and then LED off
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

some times red led will flash on pro micro board , dis-connect 360 controller also keep red led flash
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

Material status
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
NXP 74HC4050D
MAX3421EE
49SMD-12M
10uf smd e-cap

if you have any idea please comment and help me for fix
many thanks Sir

hpx1984, 2022-05-13:
missed one more component is MIC5219-3.3BM5(marking:LG33)

Ryzee119, 2022-06-06:
The two lights on solid would indicate that is it working to me? Any news on this?

hpx1984, 2022-06-18:
now my ogx360 can worked now ,after i use another crystal oscillator
but i got another problem
i use orange 8bitdo adaptor for pairing one PS4 controller and it can worked fine , then i add one more Arduino board for support 2nd controller but i can't pairing the 2nd PS4 controller , tried 2.1 and 2.15 FW and got same issue

hpx1984, 2022-06-18:
360 controller can pairing 2sets, very thing fine , thanks your great project Sir

Closed 2022-06-18.

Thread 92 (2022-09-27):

original breaout boards

lucirgo, 2022-09-27:
hello, Ryzee119 thanks for all the hard work.

i know the original breakout boards is in another project but I want to ask you directly and no thru tek,

I order from jlcpcb all the boards and the break out is not working correctly already, tried to solder 2 of them with no luck they look like they have a short circuit, I was thinking that probably I mess the micro sub soldering as these are the smallest but I tried to solder 1 without the MicroUSB to test, this board has the same issue, so do you know if there any issue with this board design or maybe It can't be repaired may be ripping some traces.

already test using the external USB connector thru the controller port and xbox360 works great I love it so far.

best regard

Ryzee119, 2023-04-07:
Not sure what you mean by breakout boards but the ogx360 PCBs have been built by hundreds of people without issues. So it is likely a soldering issue.

Closed 2023-04-07.

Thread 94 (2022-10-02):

Wireless Xbox Controllers via USB Cable

XeniumMods, 2022-10-02:
While I was doing some testing on the OGX360, I remembered
there were cables for the Xbox360 so that you could connect
a wireless controllers to the console, possibly for rechargeable
batteries. Not having one to test I thought if something similar
could be done with XboxONE and Series X/S wireless controllers.
Using an Elite 1 (1698) and Series X (1914) controllers, I connected
them to the OGX360 via USB cables I found that they both did
register some button presses but for the most part it would not
work as you might expect.

Is this something that can be implemented?

Ryzee119, 2022-10-02:
Pretty sure wireless 360 usb cables are purely charging?

Can you check if it works on a windows PC?

XeniumMods, 2022-10-02:
That's what I thought. [Xbox Support: Connect Controller to PC](https://support.xbox.com/en-AU/help/hardware-network/controller/connect-xbox-wireless-controller-to-pc)
I got them both to work on PC and tested them over at [gamepad-tester.com](https://gamepad-tester.com/)
But I had to use different cables for them in order for Windows to detect them properly.
Came across a [YouTube video](https://www.youtube.com/watch?v=kzJ2vh58KQ4) that discusses issues with some USB cables.
After this I retested both controllers using the new cables. The XboxONE Elite controller
worked fine and was surprised to see that my presets my the paddles were still there.
The Series X controller does work now but some buttons are not as responsive.
I went back to the PC and tested this controller again to see if it might be the cable
but it seems to be alot more responsive on the PC that it does on the OGX360.

Ryzee119, 2022-10-02:
Are you using the latest fw? V2.15 fixes some issues with xbox s/x controllers

XeniumMods, 2022-10-03:
I just updated my Series X controller using my Series X console,
not sure what version the firmware is but the issues persist.
It could be the cable I'm using but it's the Xbox USB cable that
came with my Elite 2 controller so you would expect it to work.
Unfortunately I don't have much in the way of Type A to Type C
cables to test any further at this stage...

I'm wondering if zeroing out those dropping resistors on the
data lines just behind the Type-A port would help?
I noticed on the tinyogx360 they were removed completely.

Ryzee119, 2022-10-03:
I mean ogx360 firmware v2.15

XeniumMods, 2022-10-03:
Oh right, sorry my mind was else where.
Confirmed that firmware v2.15 did the trick.
Not sure which version I was using...

Thanks again

Closed 2023-04-07.

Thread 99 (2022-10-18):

issues getting 3 parts for the OGX360

Jonnycake99, 2022-10-18:
Having issues getting 3 parts for the OGX360 from digikey and alternative places.
Can anyone help me get substitutes that wont damage the circuit.

Reference (U2)                 74HC4050DCT-ND
Reference (D1,D2,D3)      1727-7328-1-ND
Reference (U3)                  576-1281-1-ND

Thanks,

yankz12, 2022-10-26:
Hey Jonny,

I uploaded an item list with current availabilites which applies for Mouser & Digikey in Germany:
[availability_items.ods](https://github.com/Ryzee119/ogx360/files/9870028/availability_items.ods)

Where do you try to order from? Depending on the country, availabilites can differ. If I split the parts in two different orders, I can buy everything except for the Schottky Diodes (BAT54GWJ). I did some research via Digikey and the part which is closest to the BAT54GWJ is the BAT43W-E3-08. Differences are:

- Higher Voltage - Forward: 450 mV @ 15 mA instead of 400 mV @ 10 mA
- Smaller Current - Reverse Leakage: 500 nA @ 25 V instead of 2 µA @ 25 V
- Smaller Capacitance: 7pF @ 1V, 1MHz instead of 10pF @ 1V, 1MHz

By substituting the Diode with the BAT43W-E3-08 ones, are there any issues that could arise? Or is this safe to apply? Sorry, I dont have much of a clue regarding Diodes...

Kind regards,
yankz

bvinson9, 2022-11-28:
I can confirm I have sourced all components for making 4 or 5 complete 4 port OGX360's the only parts I can't get are the BAT54GWJ Diodes. I even ordered 25 of them from Newark.com and was shipped an empty envelope. They took some prodding, but refunded me. Then I reordered and was emailed that my order will be shipped after 07/18/2023.

I was looking at BAT42W-G3-08 on mouser.com. I'm not even close to knowing how to make this circuit work w/o proper supervision. Hoping to get some help here. Please.

locutus2000, 2023-01-30:
Would BAT42W-E3-08 be a suitable replacement? BAT54GJ is still not available (at least not digi-key).

https://www.digikey.nl/en/products/detail/vishay-general-semiconductor-diodes-division/BAT42W-E3-08/3104176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

Closed 2023-04-07.

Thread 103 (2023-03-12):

MAX3421 invalid data read

CITRUS-Laim, 2023-03-12:
I connected max3421 via 74hc125
I have this error on test:
Ryzee119
ogx360 Testing Routine
Based on test routine by Circuits At Home
See https://github.com/felis/USB_Host_Shield_2.0/blob/master/examples/board_qc/board_qc.ino
MAX3421 Revision 03
SPI bus integrity test. Transfers 1MB of data. Each dot is 64K
Test failed.  Value written: 01 read: 00
Unrecoverable error - test halted!!
0x55 pattern is transmitted via SPI
Press RESET to restart test

Ryzee119, 2023-04-07:
must be board error, soldering issue, faulty component. Can tell with information provided.

Closed 2023-04-07.

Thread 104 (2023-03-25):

"Waiting for device" problem

Miggas, 2023-03-25:
Hi, I've made a custom board and after assembling it and testing, no controllers where detected, I've already triple checked all connections to make sure everything is connected to the right pin and the solder joints are good, but I'm still getting this issue,
it stops on "Waiting for device" and stays there even with other controllers.
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

Edit: I can upload my eagle files if you want to take a look

Miggas, 2023-03-26:
[custom pcb.zip](https://github.com/Ryzee119/ogx360/files/11070542/custom.pcb.zip)
Here's the files anyway

Ryzee119, 2023-03-26:
I can't really provide support for custom boards but check the USB port is getting 5V and the D+/- are the right way around

Miggas, 2023-04-10:
Took a while, but I've found the problem, the voltage regulator ic was faulty and was supplying 4.9v instead of 3.3v, I replaced it and now it works fine. Even though the issue is closed, I'll leave this info here to help someone in case of the same problem.

Closed 2023-04-07.

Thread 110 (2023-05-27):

Steel Battalion Controler Emulation support for the Game "Steel Battalion - Line of Contact"?

xfortknoxX, 2023-05-27:
Thanks for your recent help here:
[https://github.com/Ryzee119/ogx360/issues/105](url)

I finally got a QWERTY Layout chatpad and the Singleplayer Game "Steel Battalion" works fine with it. 👍

Now I wonder wether the Steel Battalion controller emulation is compatible in its current state with the Game "Steel Battalion - Line of Contact"?

Cause after I tried it, it seems to recognize the controller properly at first (I can press successfully press the "main weapon button" and get to the main menu of the game)
But after choosing
"Xbox Live"
or
"System Link"
I always get this error and cannot continue:

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

Switching back to the duke and then back to the controller Emulation didn't solve the issue for me.

You have the same issue? Or is this game simply not yet compatible?

Thank you in advance Ryzee119

Info:
I'm using an ogx360 with the latest FW

Ryzee119, 2023-05-27:
I have a feeling that games needs a normal controller in one port. Can you try a normal controller on port 1 and ohx360 on the other port?

xfortknoxX, 2023-05-27:
Thank you for the fast response.
Good idea. I'll try that out later and give you my feedback then.
Greetings

xfortknoxX, 2023-05-27:
You were right.
I connected a common wireless controller to ogx360 port 1 and connected the controller with the chatpad to the second port.
Then it worked flawlessly.

Strange behavior. Are there other games in existance with the same requirements?

Thank you for everything ☺️

Ryzee119, 2023-05-27:
Not that I'm aware of. That game just expect a controller to navigate menus and you wouldn't normally unplug it and connect your steel battalion controller back and forward

Closed 2023-05-27.

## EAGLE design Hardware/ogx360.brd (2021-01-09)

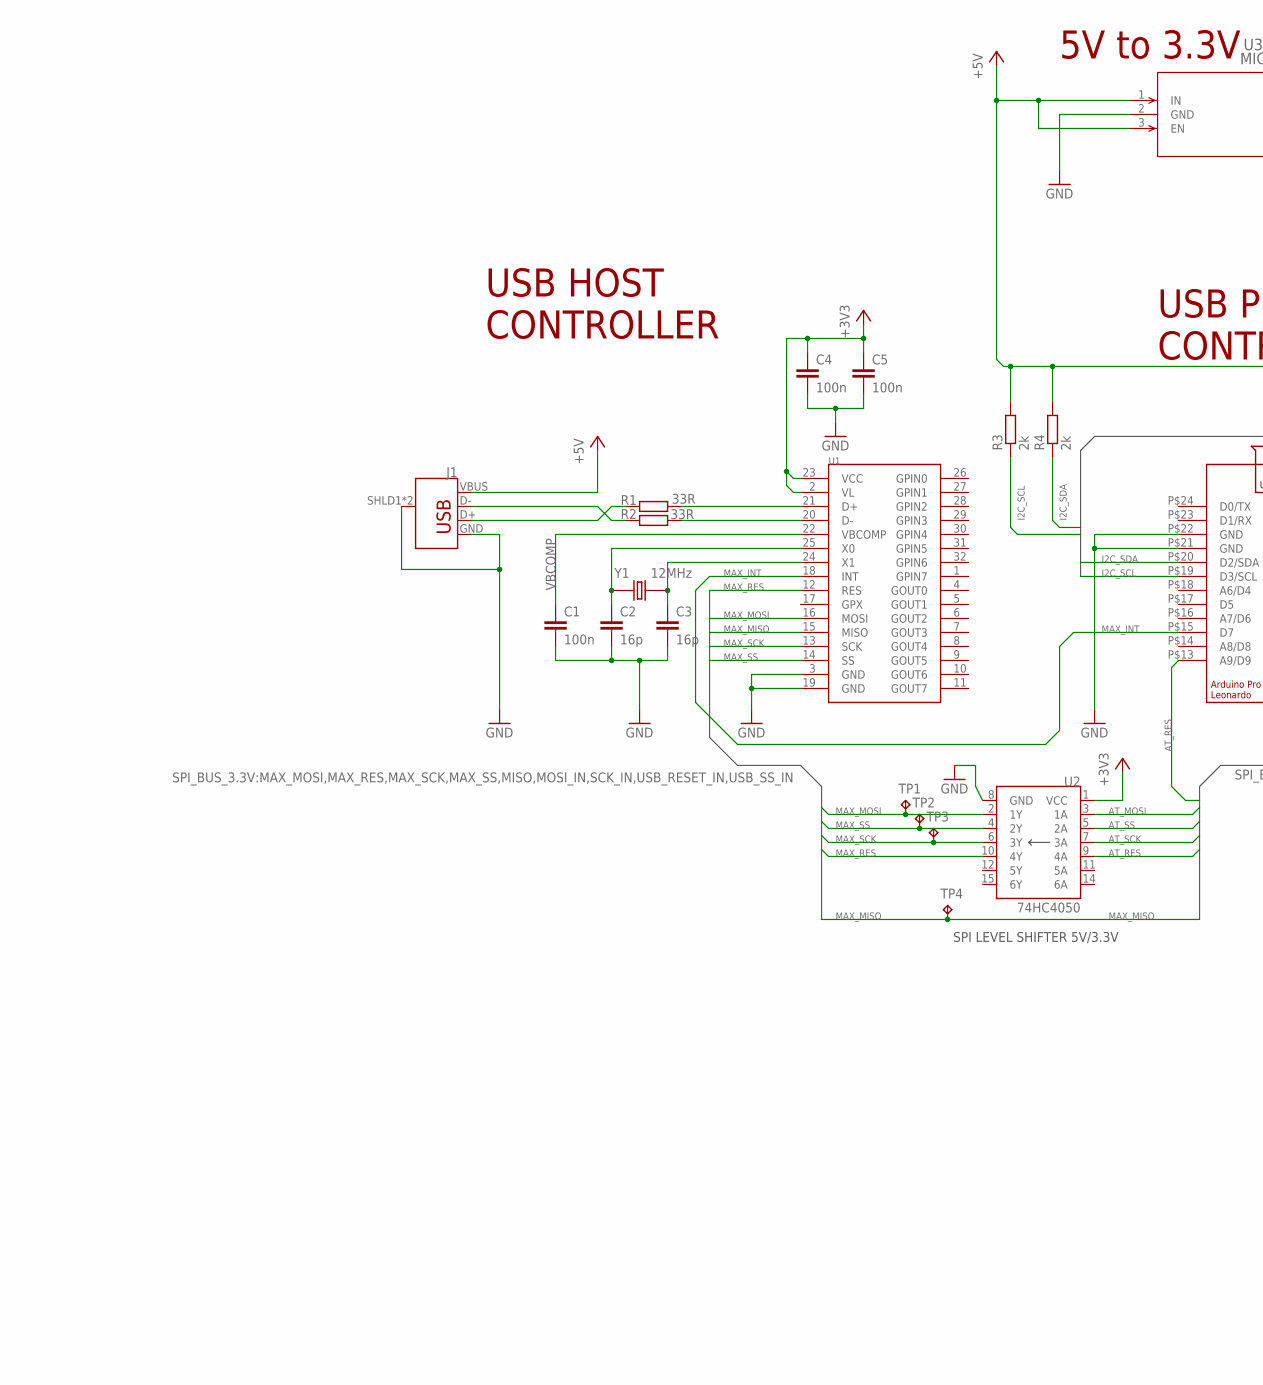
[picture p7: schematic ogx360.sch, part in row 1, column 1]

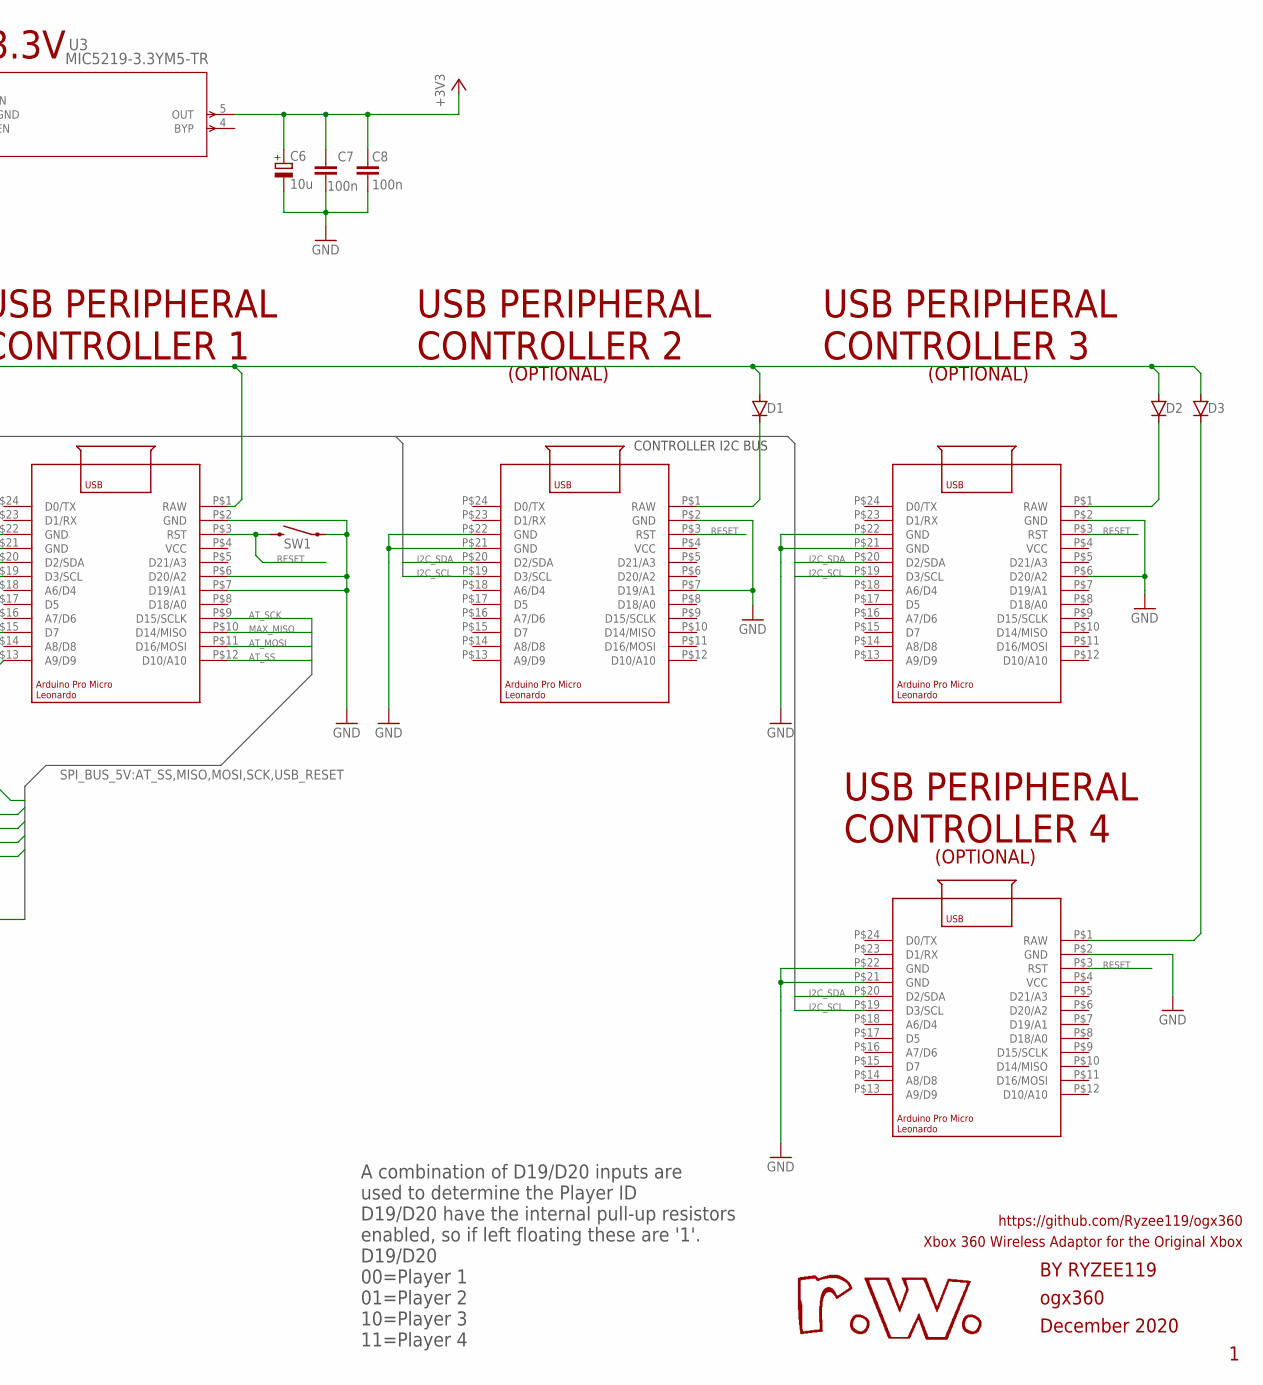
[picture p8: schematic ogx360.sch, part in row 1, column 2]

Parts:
C1, C4, C5, C7, C8: 100n; C0805
C2, C3: 16p; C0805
C6: 10u; 153CLV-0405
D1, D2, D3: DIODE-SOD123; SOD123
J1: USB_A_SMT_FEMALE_NS; USB-A-S-NOSILK-FEMALE
R1, R2: 33R; R0805
R3, R4: 2k; R0805
SW1: TL3305AF160QG
TP1, TP2, TP3, TP4: TPTP10R; TP10R
U1: MAX3421ETQFP32-5MM; TQFP32-5X5MM
U2: 74HC4050; SO16
U3: MIC5219-3.3YM5-TR; SOT-23-5_M5_MCH
U4, U5, U6, U7: ARDUINO_LEONARDO_MICRO
Y1: 12MHz; XTAL_ECS-250-18-5PX-JEM-TR

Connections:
+3V3: C4.1, C5.1, C6.+, C7.1, C8.1, U1.2 (VL), U1.23 (VCC), U2.1 (VCC), U3.5 (OUT)
+5V: D1.A, D2.A, D3.A, J1.VBUS, R3.2, R4.2, U3.1 (IN), U3.3 (EN), U4.P$1 (RAW)
+5V_SLAVE1: D1.C, U5.P$1 (RAW)
+5V_SLAVE2: D2.C, U6.P$1 (RAW)
+5V_SLAVE3: D3.C, U7.P$1 (RAW)
AT_MOSI: U2.3 (1A), U4.P$11 (D16/MOSI)
AT_RES: U2.9 (4A), U4.P$13 (A9/D9)
AT_SCK: U2.7 (3A), U4.P$9 (D15/SCLK)
AT_SS: U2.5 (2A), U4.P$12 (D10/A10)
D_N: R2.1, U1.20 (D-)
D_P: R1.1, U1.21 (D+)
GND: C1.2, C2.2, C3.2, C4.2, C5.2, C6.-, C7.2, C8.2, J1.GND, J1.SHLD1 (SHIELD), J1.SHLD2 (SHIELD), SW1.P$3 (2), SW1.P$4 (2), U1.3 (GND), U1.19 (GND), U2.8 (GND), U3.2 (GND), U4.P$2 (GND), U4.P$6 (D20/A2), U4.P$7 (D19/A1), U4.P$21 (GND), U4.P$22 (GND), U5.P$2 (GND), U5.P$7 (D19/A1), U5.P$21 (GND), U5.P$22 (GND), U6.P$2 (GND), U6.P$6 (D20/A2), U6.P$21 (GND), U6.P$22 (GND), U7.P$2 (GND), U7.P$21 (GND), U7.P$22 (GND)
I2C_SCL: R3.1, U4.P$19 (D3/SCL), U5.P$19 (D3/SCL), U6.P$19 (D3/SCL), U7.P$19 (D3/SCL)
I2C_SDA: R4.1, U4.P$20 (D2/SDA), U5.P$20 (D2/SDA), U6.P$20 (D2/SDA), U7.P$20 (D2/SDA)
MAX_INT: U1.18 (INT), U4.P$15 (D7)
MAX_MISO: TP4.TP, U1.15 (MISO), U4.P$10 (D14/MISO)
MAX_MOSI: TP1.TP, U1.16 (MOSI), U2.2 (1Y)
MAX_RES: U1.12 (RES), U2.10 (4Y)
MAX_SCK: TP3.TP, U1.13 (SCK), U2.6 (3Y)
MAX_SS: TP2.TP, U1.14 (SS), U2.4 (2Y)
unnamed: J1.D+, R1.2
unnamed: J1.D-, R2.2
unnamed: C2.1, U1.25 (X0), Y1.1
unnamed: C3.1, U1.24 (X1), Y1.2
RESET: SW1.P$1, SW1.P$2, U4.P$3 (RST), U5.P$3 (RST), U6.P$3 (RST), U7.P$3 (RST)
VBCOMP: C1.1, U1.22 (VBCOMP)

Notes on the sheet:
USB HOST CONTROLLER
ogx360
December 2020
BY RYZEE119
Xbox 360 Wireless Adaptor for the Original Xbox
https://github.com/Ryzee119/ogx360
USB PERIPHERAL CONTROLLER 1
USB PERIPHERAL CONTROLLER 2
5V to 3.3V
A combination of D19/D20 inputs are used to determine the Player ID D19/D20 have the internal pull-up resistors enabled, so if left floating these are '1'. D19/D20 00=Player 1 01=Player 2 10=Player 3 11=Player 4
USB PERIPHERAL CONTROLLER 3
USB PERIPHERAL CONTROLLER 4
(OPTIONAL)
CONTROLLER I2C BUS
SPI LEVEL SHIFTER 5V/3.3V

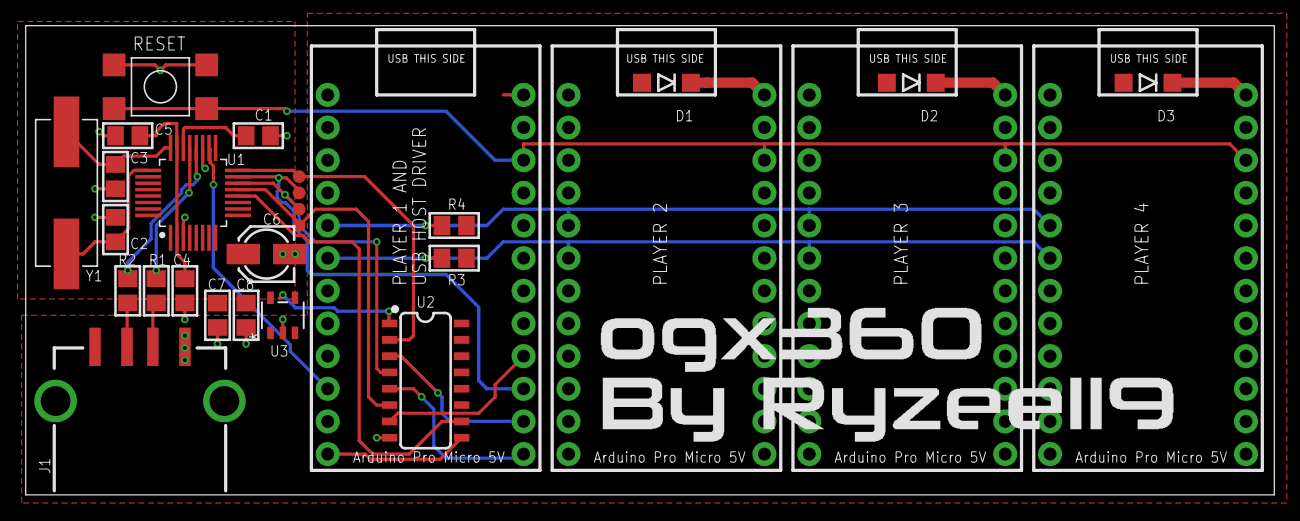
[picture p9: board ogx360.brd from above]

Board: 2 copper layers, 97.1 x 36.5 mm, 29 parts (0 on the bottom side), 26 nets.

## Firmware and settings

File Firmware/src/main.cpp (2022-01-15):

// Copyright 2021, Ryan Wendland, ogx360
// SPDX-License-Identifier: GPL-3.0-or-later

#include <Arduino.h>

#include "main.h"
#include "usbd/usbd_xid.h"
#include "usbh/usbh_xinput.h"

uint8_t player_id;
XID_ usbd_xid;
usbd_controller_t usbd_c[MAX_GAMEPADS];

void setup()
{
    Serial1.begin(115200);

    pinMode(ARDUINO_LED_PIN, OUTPUT);
    pinMode(PLAYER_ID1_PIN, INPUT_PULLUP);
    pinMode(PLAYER_ID2_PIN, INPUT_PULLUP);
    digitalWrite(ARDUINO_LED_PIN, HIGH);

    memset(usbd_c, 0x00, sizeof(usbd_controller_t) * MAX_GAMEPADS);

    for (uint8_t i = 0; i < MAX_GAMEPADS; i++)
    {
        usbd_c[i].type = DUKE;
        usbd_c[i].duke.in.bLength = sizeof(usbd_duke_in_t);
        usbd_c[i].duke.out.bLength = sizeof(usbd_duke_out_t);

        usbd_c[i].sb.in.bLength = sizeof(usbd_sbattalion_in_t);
        usbd_c[i].sb.out.bLength = sizeof(usbd_sbattalion_out_t);
    }

    //00 = Player 1 (MASTER)
    //01 = Player 2 (SLAVE 1)
    //10 = Player 3 (SLAVE 2)
    //11 = Player 4 (SLAVE 3)
    player_id = digitalRead(PLAYER_ID1_PIN) << 1 | digitalRead(PLAYER_ID2_PIN);

    if (player_id == 0)
    {
        master_init();
    }
    else
    {
        slave_init();
    }
}

void loop()
{
#if (0)
    //Performance loop timing.
    //Four slaves, four wireless controllers is about 4000us per loop
    //Perfect!
    static uint32_t loop_cnt = 0;
    static uint32_t loop_timer = 0;
    if (loop_cnt > 1000)
    {
        Serial1.print("Loop time: (us) ");
        Serial1.println(millis() - loop_timer);
        loop_cnt = 0;
        loop_timer = millis();
    }
    loop_cnt++;
#endif

    if (player_id == 0)
    {
        master_task();
    }
    else
    {
        slave_task();
    }

    //Handle OG Xbox side (OG Xbox)
    if (usbd_xid.getType() != usbd_c[0].type)
    {
        usbd_xid.setType(usbd_c[0].type);
    }

    static uint32_t poll_timer = 0;
    if (millis() - poll_timer > 4)
    {
        if (usbd_xid.getType() == DUKE)
        {
            UDCON &= ~(1 << DETACH);
            RXLED1;
            usbd_xid.sendReport(&usbd_c[0].duke.in, sizeof(usbd_duke_in_t));
            usbd_xid.getReport(&usbd_c[0].duke.out, sizeof(usbd_duke_out_t));
        }
        else if (usbd_xid.getType() == STEELBATTALION)
        {
            UDCON &= ~(1 << DETACH);
            RXLED1;
            usbd_xid.sendReport(&usbd_c[0].sb.in, sizeof(usbd_sbattalion_in_t));
            usbd_xid.getReport(&usbd_c[0].sb.out, sizeof(usbd_sbattalion_out_t));
        }
        else if (usbd_xid.getType() == DISCONNECTED)
        {
            UDCON |= (1 << DETACH);
            RXLED0;
        }

        poll_timer = millis();
    }
}

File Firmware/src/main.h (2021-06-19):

// Copyright 2021, Ryan Wendland, ogx360
// SPDX-License-Identifier: GPL-3.0-or-later

#ifndef _MAIN_H_
#define _MAIN_H_

#include "usbd/usbd_xid.h"
#include "usbh/usbh_xinput.h"

#ifndef MAX_GAMEPADS
#define MAX_GAMEPADS 4
#endif

#define USB_HOST_RESET_PIN 9
#define ARDUINO_LED_PIN 17
#define PLAYER_ID1_PIN 19
#define PLAYER_ID2_PIN 20

#ifndef SB_DEFAULT_SENSITIVITY
#define SB_DEFAULT_SENSITIVITY 400
#endif

typedef struct
{
   xid_type_t type;
   usbd_duke_t duke;
   usbd_steelbattalion_t sb;
} usbd_controller_t;

void master_init();
void master_task();
void slave_init();
void slave_task();

#endif 

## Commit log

2019-01-06 Fixed rare rumble bug and soft reset bug
    [main.cpp]
2019-01-27 Swapped black and white buttons
    [main.cpp]
2019-01-28 Added Arduino clone ref
2019-03-11 Added Rumble Feedback to SB, Tweaked SB Button Mapping, bug Fixes, Optimizations. SB Protocol Notes
    [main.cpp]
2019-03-22 Added another case
2019-04-09 8bitdo adaptor support, tweak SB controller mapping, added SB ssensitivity adjust, Wired 360 in main firmware now
2019-06-20 Added PID 0x2AA for a new wireless receiver found by users
2019-07-04 Fixed rumble pipe for 8btido controllers, gitinore and editorconfig added, formatting etc.
    [main.cpp]
2019-08-02 Updated part for LED. Refer Issue #9
2019-08-24 Code clean up, fixed some back end stuff. Xbox 360 wireless init sequence closer to genuine, polls slaves on power up to confirm they're presetn
    [main.cpp]
2019-08-28 Fixed issue #12, Fixed THPS 2X rumble issue, Fixed XblastOS hotplug issue
    [main.cpp]
2019-09-21 Added PID 0x02A9
2019-10-24 added VID=0x0738 PID=0x4738
2020-03-15 Added hyperkin duke, alot of code refactoring, fixed bug in xbox one driver
    [main.cpp]
2020-05-24 Update and fix GameStop and Afterglow wired controllers VID/PID values.
2020-05-26 Added madcatz wired controller vid/pid, thrustmaster wired controller vid/pid and thrustmaster wheel vid/pid. All three tested and working.
2020-12-11 XBOXRECV: Fix incorrect chatpad button states
2020-12-11 XBOXRECV: Refresh LED periodically
2020-12-11 Main: Fix order of USBTask. Slight improvment in input lag
    [main.cpp]
2020-12-11 XBOXRECV: Out pipe timer should be static
2020-12-13 XBOXUSB Add support to v1.14 wired controller & minor bug fix
2020-12-27 Rumble fix for Steel Battalion
    [main.cpp]
2021-01-09 HW: PCB to revision 1
    [ogx360.brd, ogx360.sch]
2021-01-09 HW: Migrate to kitspace
    [bom.csv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]
2021-01-09 BOM: Fix unknown characters
    [bom.csv]
2021-01-09 BOM: Remove Arduino link
    [bom.csv]
2021-01-09 HW: Route reset trace
    [ogx360.brd, ogx360.sch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]
2021-01-09 Images: Add revised PCB photo
2021-01-09 README: Update image to latest PCB
2021-01-09 HW: Update schematic image
2021-01-09 Main: Add ability to invert right stick Y-axis
    [main.cpp]
2021-02-12 XBOXONE: Add Xbox S/X PID 0x0B12 support
2021-02-15 Input: Allow inverstion of X and Y axis on right stick.
2021-06-19 Core: Add ArduinoCore as a submodule
2021-06-19 USBD: Remove legacy usbd driver
2021-06-19 USBH: Add initial xinput driver
2021-06-19 USBD: Add PluggableUSB XID driver
2021-06-19 Input: Allow inversion of RS x and y axis
2021-06-19 Input: Rework Steel Battalion
    [main.cpp, master.cpp]
2021-06-19 Input: Remove gear lever init from main
2021-10-02 USBD: Fix enum typo
    [main.cpp, master.cpp, slave.cpp]
2022-01-15 Main: Make LEDs behave like legacy firmware
2022-01-15 USBH: Manually probe USB bus too
2022-01-15 XINPUT: Correctly handle devices with multiple interfaces
    [usbh_xinput.cpp]
2022-01-15 XINPUT: Handle 8bitdo wireless adaptor 2
2022-05-30 xinput: Add init packets for PowerA branded xbone controllers
2023-04-18 Make component quantities in BOM correct
    Fixes https://github.com/Ryzee119/ogx360/issues/106
    [bom.csv]

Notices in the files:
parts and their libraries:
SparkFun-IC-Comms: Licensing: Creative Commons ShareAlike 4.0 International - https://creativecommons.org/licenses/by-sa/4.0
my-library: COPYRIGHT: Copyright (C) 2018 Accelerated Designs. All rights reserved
